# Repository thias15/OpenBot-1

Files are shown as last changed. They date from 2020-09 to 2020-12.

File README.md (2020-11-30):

<a href="https://www.openbot.org/" target="_blank">
  Banner
</a>

<h1 align="center"><a>Turning Smartphones into Robots</a></h1>

<p align="center">
   </a>
   </a>
   </a>
   </a>
   </a>
   </a>
   </a>
   </a>
</p>

<p align="center">
  <span>English</span> |
  <a href="README_CN.md">简体中文</a>
</p>

OpenBot leverages smartphones as brains for low-cost robots. We have designed a small electric vehicle that costs about $50 and serves as a robot body. Our software stack for Android smartphones supports advanced robotics workloads such as person following and real-time autonomous navigation.

## Get started with OpenBot
- Build your own [Robot Body](body/README.md)
- Flash the [Arduino Firmware](firmware/README.md)
- Install the [Android App](android/README.md)
- Train your own [Driving Policy](policy/README.md)

## Get the source code

- You can download the repo as a [zip file](https://github.com/intel-isl/OpenBot/archive/master.zip) and extract it into a folder of your choice.
- You can clone the OpenBot repository from GitHub with the following command:
    ```bash
    git clone https://github.com/intel-isl/OpenBot.git
    ```
- You can fork the OpenBot repository and then clone your local copy. This is recommended, especially if you want to [contribute](CONTRIBUTING.md).

## Citation

Please cite our [paper](docs/paper/OpenBot.pdf) if you use OpenBot.

```bib
@article{openbot2020,
    author    = {Matthias M\"uller and Vladlen Koltun},
    title     = {{OpenBot}: Turning Smartphones into Robots},
    journal   = {arXiv:2008.10631},
    year      = {2020},
}
```

## Video

<a href="https://www.youtube.com/watch?v=qc8hFLyWDOM" >
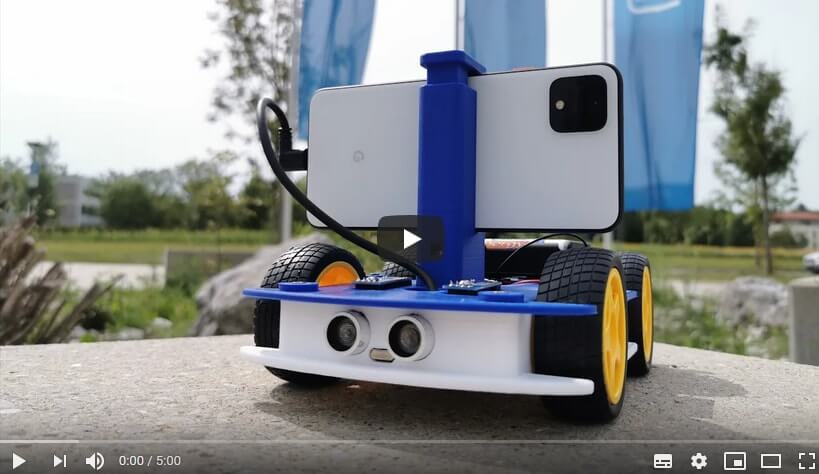
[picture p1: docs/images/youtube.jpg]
youtube video
  
</a>

## Contribute

Please read the [contribution guidelines](CONTRIBUTING.md). If you are not sure where to start have a look at the [open issues](https://github.com/intel-isl/OpenBot/issues).

## Contact

- Join our [Slack](https://join.slack.com/t/openbot-community/shared_invite/zt-jl8ygxqt-WNRNi9yzh7Lu60qui6Nh6w) channel to connect with the OpenBot community.
- Contact us via [Email](mailto:openbot.team@gmail.com)

<a href="https://www.openbot.org//" target="_blank">
  Footer
</a>

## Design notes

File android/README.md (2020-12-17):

# Android App

<p align="center">
  <span>English</span> |
  <a href="README_CN.md">简体中文</a>
</p>

Our application is derived from the [TensorFlow Lite Object Detection Android Demo](https://github.com/tensorflow/examples/tree/master/lite/examples/object_detection/android). We add a data logger and support for game controllers to collect datasets with the robot. Currently, we record readings from following sensors: camera, gyroscope, accelerometer, magnetometer, ambient light sensor, and barometer. Using the Android API, we are able to obtain the following sensor readings: RGB images, angular speed, linear acceleration, gravity, magnetic field strength, light intensity, atmospheric pressure, latitude, longitude, altitude, bearing, and speed. In addition to the phone sensors, we also record body sensor readings (wheel odometry, obstacle distance and battery voltage), which are transmitted via the serial link. Lastly, we record control commands received from a connected game controller, if present. We also integrate several neural networks for person following and autonomous navigation.

## DISCLAIMERS

1. **Safety:** Always make sure you operate in a safe environment. Keep in mind, that your phone could be damaged in a collision! Special 
care is neccessary when using automated control (e.g. person following or driving policy). Make sure you always have a game controller connected and are familiar with the key mapping so you can stop the vehicle at any time. Use at your own risk!
2. **App under development:** The application is under development and may crash or exhibit unexpected behaviour depending on your phone model and version of the operating system. Make sure to test all functionalities with no wheels connected. Use at your own risk!

## Getting Started

### Install the app
You can download the apk from the assets of the [latest release](https://github.com/intel-isl/OpenBot/releases/latest) and just [install](https://www.lifewire.com/install-apk-on-android-4177185) it on your phone directly. Note that that apk is signed with a debug key. If you want the latest app from the master branch, you can also download it from the build artifacts [here](https://github.com/intel-isl/OpenBot/actions?query=workflow%3A%22Java+CI+with+Gradle%22). Note, that it may not be stable. If you would like to make changes to the app later, follow the steps below to compile the app and deploy it on your phone.

### Build the app

#### Prerequisites

- [Android Studio 3.2 or later](https://developer.android.com/studio/index.html) for building and installing the apk.
- Android device and Android development environment with minimum API 21.
- Currently, we use API 28 as compile and target SDK. It should get installed automatically, but if not you can install the SDK manually. Go to Android Studio -> Preferences -> Appearance & Behaviour -> System Settings -> Android SDK. Make sure API 28 is checked and click apply.

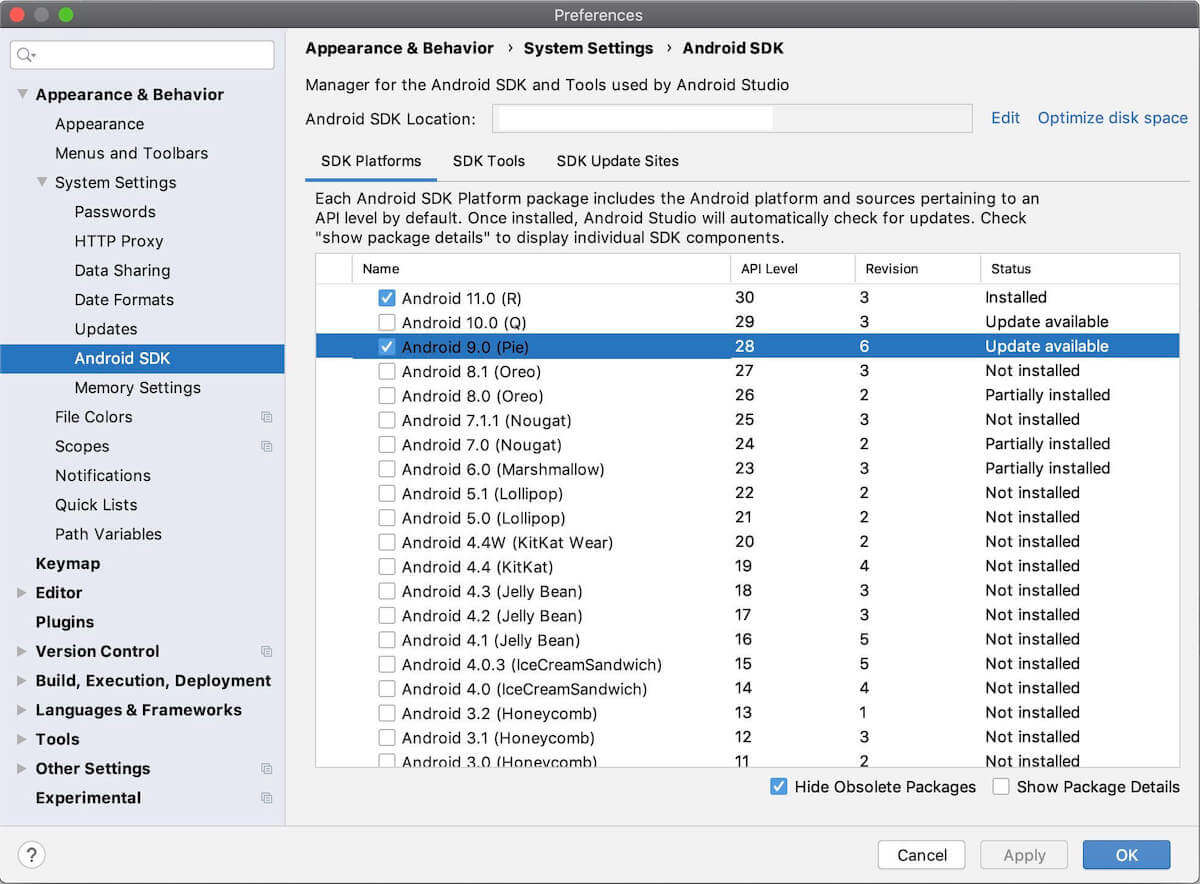
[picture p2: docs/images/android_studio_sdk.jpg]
Android SDK


#### Build process

1. Open Android Studio and select *Open an existing Android Studio project*.
2. Select the OpenBot/android directory and click OK.
3. Confirm Gradle Sync if neccessary. To perform a Gradle Sync manually, click on the gradle icon.
    Gradle Sync
4. Connect your Android device and make sure USB Debugging in the [developer options](https://developer.android.com/studio/debug/dev-options) is enabled. Depending on your development environment [further steps](https://developer.android.com/studio/run/device) might be necessary. You should see your device in the navigation bar at the top now.
  Phone
5. Click the Run button (the green arrow) or select Run > Run 'android' from the top menu. You may need to rebuild the project using Build > Rebuild Project.
  Run
6. If it asks you to use Instant Run, click *Proceed Without Instant Run*.

#### Code Structure

The [TensorFlow Lite Object Detection Android Demo](https://github.com/tensorflow/examples/tree/master/lite/examples/object_detection/android) was used as starting point to integrate TFLite models and obtain the camera feed. The main activity is the [NetworkActivity](app/src/main/java/org/openbot/NetworkActivity.java) which runs the main thread. It inherits from the [CameraActivity](app/src/main/java/org/openbot/CameraActivity.java) which manages the camera and UI. The [SensorService](app/src/main/java/org/openbot/SensorService.java) reads all other phone sensors and logs them. The [env](app/src/main/java/org/openbot/env) folder contains utility classes such as the [GameController](app/src/main/java/org/openbot/env/GameController.java) interface and an [AudioPlayer](app/src/main/java/org/openbot/env/AudioPlayer.java) for the audible feedback. The [tflite](app/src/main/java/org/openbot/tflite) folder contains the model definitions for the [Autopilot](app/src/main/java/org/openbot/tflite/Autopilot.java) and [Detector](app/src/main/java/org/openbot/tflite/Detector.java) networks.

## How to Use the App

<p align="center">
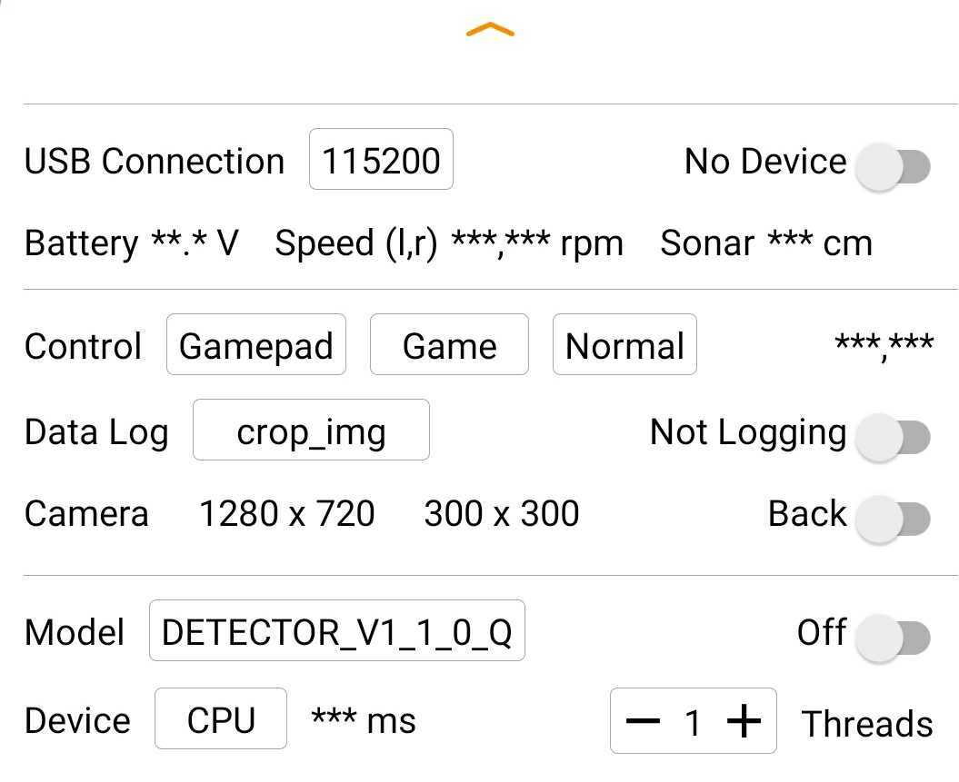
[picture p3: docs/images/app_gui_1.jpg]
  
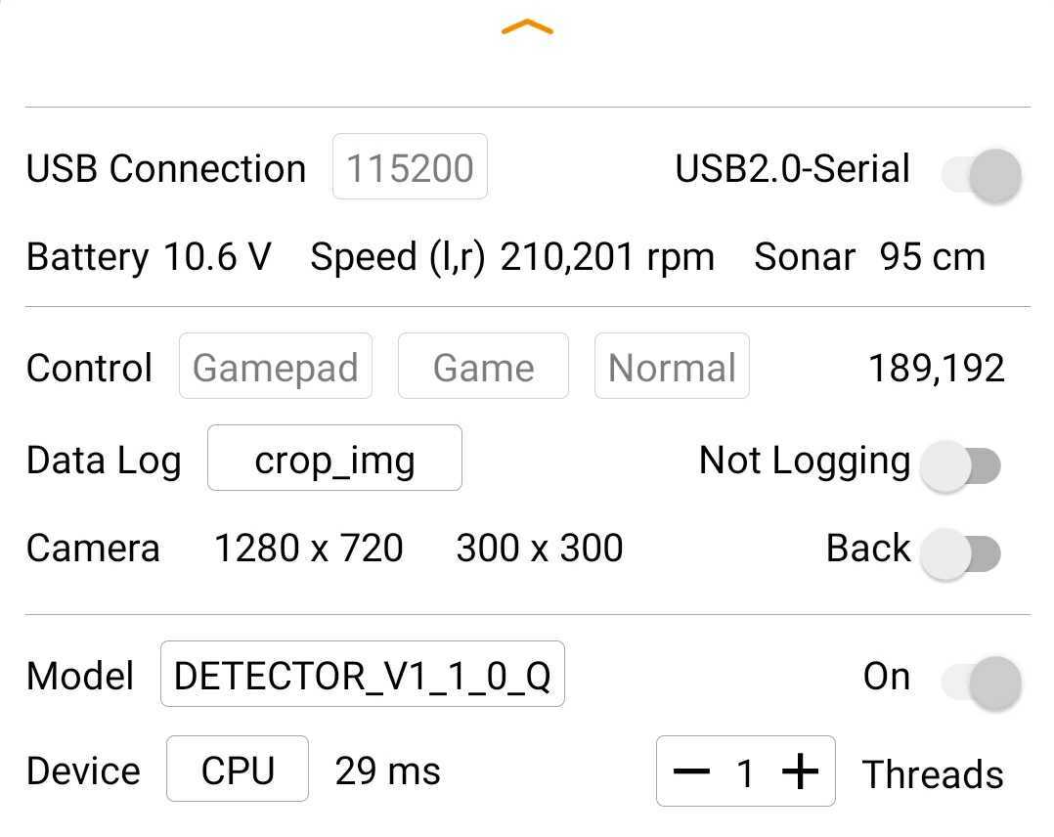
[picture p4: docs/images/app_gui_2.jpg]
  
</p>

### USB Connection

The drop-down menu is used to set the baud rate. The default is 115200 and you should not need to change this unless you mess with the Arduino firmware. The app will attempt to connect automatically, but in case you encounter issues you can use this switch to disconnect/connect.

### Vehicle Status

The field **Battery** displays the battery voltage as measured by the Arduino via the voltage divider. The field **Speed (l,r)** reports the left and right speed of the (front) wheels in rpm. It is measured by the Arduino via the optical wheel speed sensors. The field **Sonar** shows the free space in front of the car in centimeters. It is measured by the Arduino via the ultrasonic sensor. Note, you will only receive values a few seconds after the USB connections has been established.

### Control

The first button is for selecting the **control mode**. Currenlty, the only control mode is **Gamepad**. In the future, it will be possible to control the robot with another smartphone, i.e. **Phone** or via **WebRTC**. 

The second button is for selecting the **drive mode**. There are three different drive modes when using a game controller (e.g. PS4):

- **Game**: Use the right and left shoulder triggers (R2, L2) for forward and reverse throttle and either joystick for steering. This mode imitates the control mode of car racing video games.
- **Joystick**: Use either one of the joysticks to control the robot.
- **Dual**: Use the left and right joystick to control the left and right side of the car. This is raw differential steering.

The third button is for selecting the **speed mode**. There are three different speed modes:

- **Slow**: The voltage applied to the motors is limited to 50% of the input voltage (~6V).
- **Normal**: The voltage applied to the motors is limited to 75% of the input voltage (~9V).
- **Fast**: There is no limit. The full input voltage will be applied to the motors at full throttle (~12V). *This is the default setting for running the neural networks.*

Running at higher speeds will reduce the lifetime of the motors but is more fun. The controls that are sent to the robot are displayed on the right side.

### Data Log

There are four different logging modes:

- **only_sensors**: All sensor data but no images are saved.
- **crop_img**: All sensor data and a cropped images that have the input size of the network are saved. This is the default setting and is what should be used for data collection.
- **preview_img**: All sensor data and a full-size images are saved. This will require a lot of memory and can be slow. However, it is nice for compiling FPV videos.
- **all_imgs**: All sensor data and both cropped and full-size images are saved. This will require a lot of memory and can be slow.

The switch on the right is used to toggle logging on and off. On the game controller this switch can be toggled with the X button. 

### Camera

The first item shows the preview resolution. The second item shows the crop resolution. This is the image that is used as input to the neural networks. You will notice that this resolution changes depending on which model you select below. If you train your own autopilot, make sure to select the `AUTOPILOT_F` model. The crop resolution should show `256x96`. The switch on the right is used to toggle between the rear and the front camera. 

### Model

There are three models that come with the app:

- **DETECTOR_V1_1_0_Q**: This model is used for person following. It uses a SSD object detector with MobileNet V1 backbone. The model is quantized for better performance on embedded devices.
- **DETECTOR_V3_S_Q**: This model is used for person following. It uses a SSD object detector with MobileNet V3 backbone. The model is quantized for better performance on embedded devices.
- **AUTOPILOT_F**: This model is used for autonomous navigation. It will predict controls directly from the camera input. Chances are that it will not work in your environment. You should follow our instructions to train your own [Driving Policy](../policy) and replace it.

The switch on the right is used to turn the network on and off. When the network is running, it produces the controls for the robot and the game controller is disabled. However, you may still use the buttons on the game controller, for example to toggle this switch with the R1 trigger button to regain control of the robot. 

### Device

Use the drop-down menu to select the device on which the neural network should be executed. You have the following choices:

- **CPU**: Using the CPU works on most phones and is the default choice. You can adjust the number of threads to optimize performance. 
- **GPU**: Most smartphones have a GPU. Networks with large inputs such as images often run faster on a GPU.
- **NNAPI**: This will use the [TensorFlow Lite NNAPI delegate](https://www.tensorflow.org/lite/performance/nnapi). Modern smartphones often come with dedicated AI accelerators. The [Neural Network API](https://developer.android.com/ndk/guides/neuralnetworks) (NNAPI) provides acceleration for TensorFlow Lite models on Android devices with Graphics Processing Unit (GPU), Digital Signal Processor (DSP) and Neural Processing Unit (NPU). Note that on some older phones this can be very slow!

If a model is active, the inference speed in [ms] will be displayed next to the device which is running the model.

## Next (optional)

Train your own [Driving Policy](../policy/README.md)

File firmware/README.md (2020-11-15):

# Firmware

<p align="center">
  <span>English</span> |
  <a href="README_CN.md">简体中文</a>
</p>

We use a microcontroller unit (MCU) to act as a bridge between the robot body and the smartphone.  We provide our [firmware](openbot_v1_nano/openbot_v1_nano.ino) for the Arduino Nano with an ATmega328P microcontroller.

## Features

The main task of the MCU is to handle the low-level control of the vehicle and provide readings from low-level vehicle-mounted sensors. The MCU receives the vehicle controls and indicator signals via the serial connection. It converts the controls to PWM signals for the motor controller and toggles the LEDs according to the indicator signal. The Arduino program also keeps track of the wheel rotations by counting the interrupts of optical sensors on the left and right front wheels. It calculates the battery voltage by a scaled moving average of measurements at the voltage divider circuit. It can also measure the distance to obstacles in front of the car with an optional ultrasonic sensor. These measurements are sent back to the Android application through the serial link.

## Setup

First you have to set up your hardware configuration at the beginning of the code. If you did the DIY build (using the L298N motor driver), set `OPENBOT DIY`.
If you used the custom PCB, check the version and set either `OPENBOT PCB_V1` or `OPENBOT PCB_V2`.

Next, you need to configure which features you want to enable. Disabled features are not compiled to save memory and make the code faster.

- Enable the voltage divider by setting `HAS_VOLTAGE_DIVIDER 1` (default: 0)
- Enable the indicator LEDs by setting `HAS_INDICATORS 1` (default: 0)
- Enable the speed sensors by setting `HAS_SPEED_SENSORS 1` (default: 0)
- Enable the ultrasonic sensor by setting `HAS_SONAR 1` (default: 0)
- Enable the median filter for sonar measurements by setting `USE_MEDIAN 1` (default: 0)
- Enable the OLED display by setting `HAS_OLED 1` (default: 0)

### Dependencies

If you have enabled the speed sensors or the ultrasonic sensor, you need to install the [PinChangeInterrupt](https://github.com/NicoHood/PinChangeInterrupt) library. The Arduino Nano only has two external interrupt pins (D2 and D3) and D3 is also one of only six pins that support PWM. Fortunately, it also has three port interrupts that cover all pins on the Arduino. This library parses these port interrupts allowing all pins of the Arduino to be used as interrupts.

If you have enabled the OLED, you need to install the libraries [Adafruit_SSD1306](https://github.com/adafruit/Adafruit_SSD1306) and [Adafruit_GFX Library](https://github.com/adafruit/Adafruit-GFX-Library).

You can install libraries by following these steps:
1. Open the Library Manager: `Tools` :arrow_right: `Manage Libraries`
2. Enter the name of the library in the search bar.
3. Select the latest version and click install. If you have already installed the library it will show and you may be able to update it.

<p float="left">
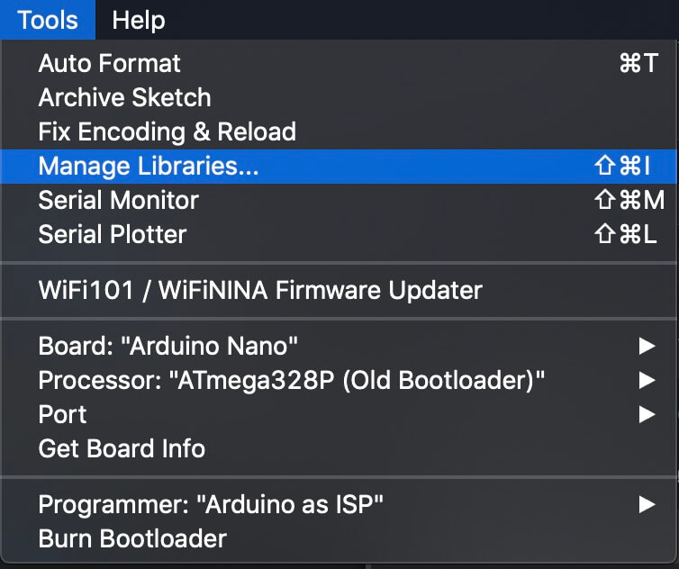
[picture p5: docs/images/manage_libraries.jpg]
  
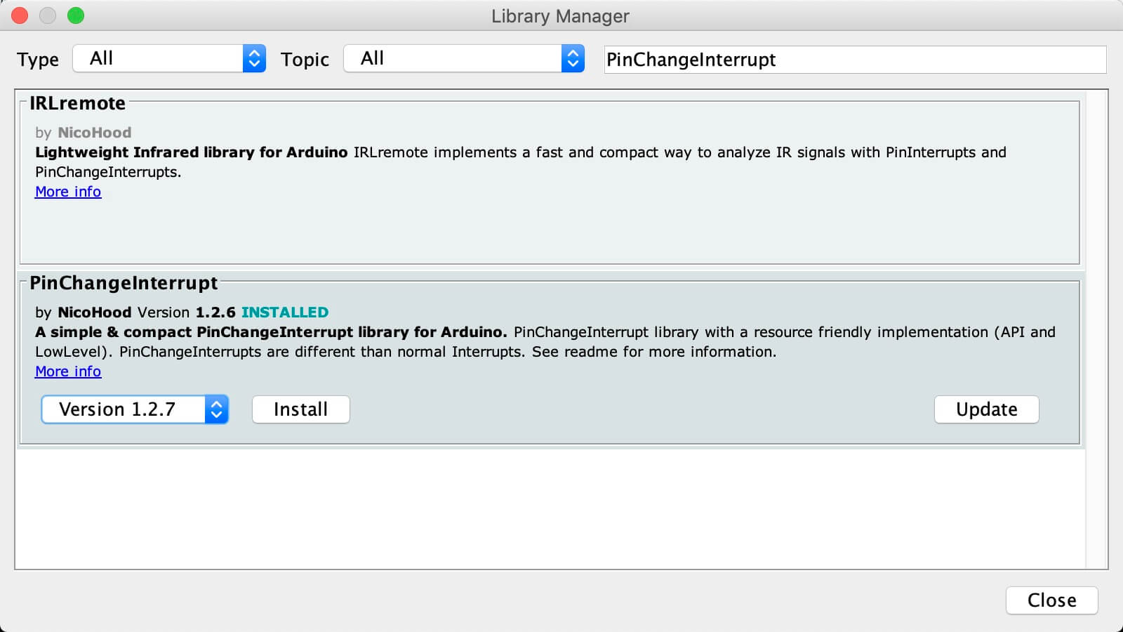
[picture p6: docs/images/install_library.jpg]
   
</p>

### Chinese clone Nano (e.g. US link)

You may need to download the [WCH340](http://www.wch.cn/product/CH340.html) drivers from the chip manufacturer (Chinese):

- [Windows](http://www.wch.cn/downloads/CH341SER_EXE.html)
- [Linux](http://www.wch.cn/download/CH341SER_LINUX_ZIP.html)
- [Mac](http://www.wch.cn/download/CH341SER_MAC_ZIP.html)

## Upload

### Settings

- `Tools` :arrow_right: `Board` :arrow_right: `Arduino AVR Boards` :arrow_right: `Arduino Nano`
- `Tools` :arrow_right: `Processor` :arrow_right: `ATmega328P (Old Bootloader)`
- `Tools` :arrow_right: `Port` :arrow_right: `*Select the USB port*`

The firmware can now be uploaded through `Sketch` :arrow_right: `Upload` or by pressing the upload button (right arrow).
Firmware Upload

:memo: NOTE: Currently, most cheap Arduino Nano boards come with the *Old Bootloader*. However, depending on the seller you may also get one with the new bootloader. So if you are unable to upload the firmware, chances are that you need to change the processor to *ATmega328P*.

### Testing

This section explains how to test all functionalities of the car after the firmware was flashed successfully.

1. Confirm that:
    1. the wheels are not connected to the car
    2. the Arduino is connected to the computer
    3. the correct USB port is selected
2. Open the Serial Monitor: `Tools` :arrow_right: `Serial Monitor`

#### Vehicle Status

You should now see four comma-seperated values that update once per second:

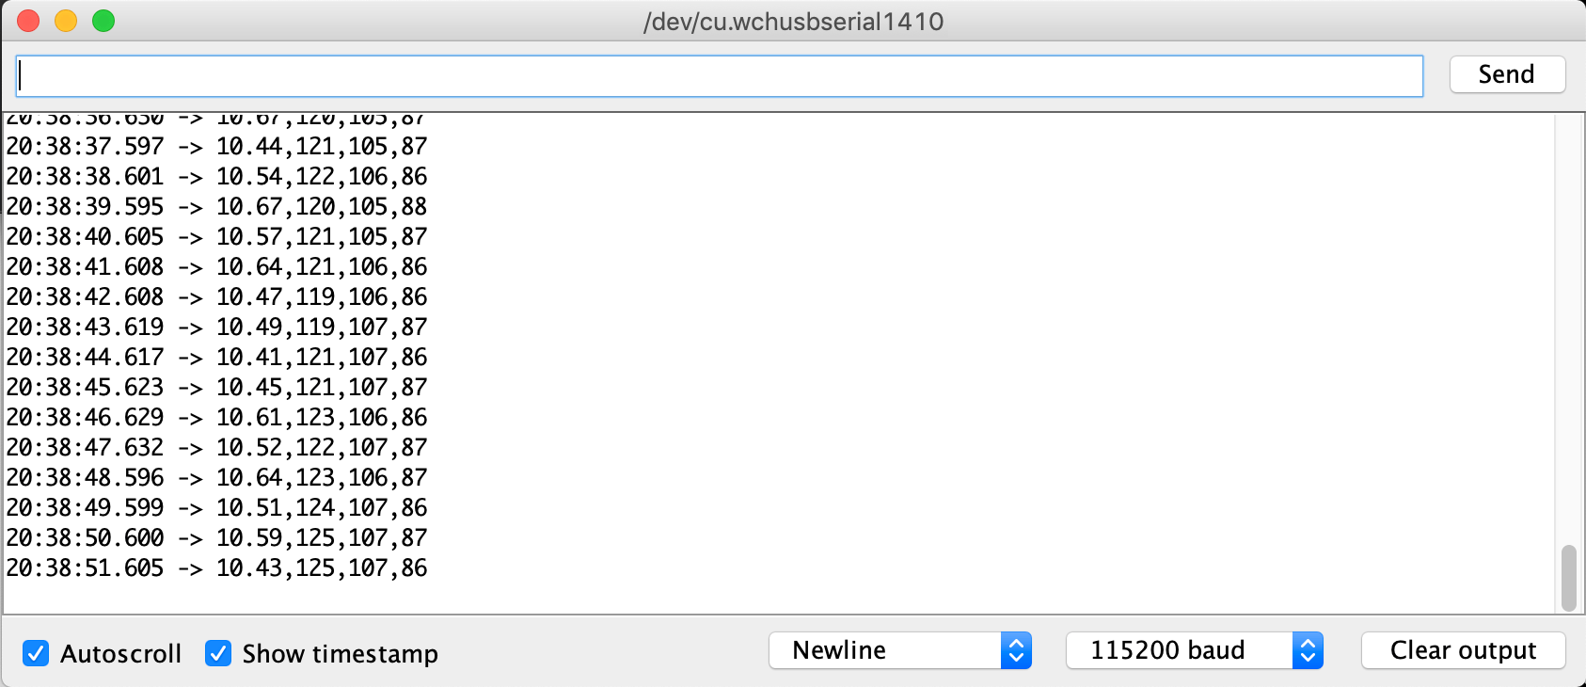
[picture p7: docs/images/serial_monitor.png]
Serial Monitor


- The first value is the battery voltage. If you connect the battery to the car (i.e. turn on the switch), it should show the battery voltage. If you disconnect the battery (i.e. turn off the switch), it should show a small value.
- The second and third values are the raw readings of the speed sensors. Each hole in the encoder disk will increment the counter by plus/minus one depending on the direction. You can set the number of holes with the parameter `DISK_HOLES`. If you are using the stardard disk with 20 holes, there will be 20 counts for each revolution of the wheel. Hence, if you divide the displayed number by 20, you will get the revolutions per second.
- The fourth value is the estimated free space in front of the ultrasonic sensor in cm. If the ultrasonic sensor is disabled or unable to get a reading, it will show `65535`.

#### Vehicle Control

You can also send messages to the Arudino by typing a command into the input field on the top and then pressing send. The following commands are available:

- `c<left>,<right>` where `<left>` and `<right>` are both in the range [-255,255]. A value of `0` will stop the motors. A value of `255` applies the maximum voltage driving the motors at the full speed forward. Lower values lead to proportionlly lower voltages and speeds. Negative values apply the corresponding voltages in reverse polarity driving the motors in reverse.
- `i<cmd>` where `<cmd>` is in the range [-1,1]. A value of `-1` turns on the left indicator LED and a value of `1` turns on the right indicator LED. A value of `0` turns the indicator LEDs off. Only one state at a time is possible.

#### Test procedure

Before you proceed, make sure the tires are removed. You will need the Serial Monitor open to send commands and you will see the messages received from your OpenBot. If you have the OLED display installed, you will also see the vehicle status displayed there in a more human-readable format. The following test procedure can be used to test all functionalities of the car:

1. Turn on the car and observe the battery voltage (first value). You can verify the reading with a multimeter and adjust the `VOLTAGE_DIVIDER_FACTOR` if neccessary.
2. If you have a ultrasonic sensor installed:
    1. Hold your hand in front of the sensor and move it back and forth. You should see the readings (fourth value) change correspondingly.
    2. We have observed that the ultrasonic sensor is very sensitive to vibrations! So it is advisable to make sure you will get reliable readings during operation by performing the following test:
        1. Place the OpenBot with the ultrasonic sensor installed such that there is at least 200cm of free space in front of it. You should see a reading of `200` or more.
        2. Observe the readings on the serial monitor for some time and then enter the command `c128,128`.
        3. If the sensor readings change significantly, you will need to dampen the vibrations transmitted to the ultrasonic sensor from the chassis (e.g. add some silicon, adjust the mounting position).
3. If you have the speed sensors installed:
    1. Make sure, you have plenty of free space in front of the ultrasonic sensor. The reading (fourth value) needs to be at least above the `STOP_THRESHOLD` which is `32` by default. If the ultrasonic sensor is not installed, you should see a reading of `65535`.
    2. Send the command `c128,128`. The motors will start spinning at *slow speed* (50% PWM). The speed sensor readings (second and third value) should be similar to the values in the image above. If you are using the DIY version or a weaker battery, values may be lower. Check that all motors are spinning forward and that the speed sensor readings are positive. Note: If you multiply these values by 3, they correspond to the rpm for the standard disk with 20 holes.
    3. Try sending different controls and observe the speed sensor readings. For example, the command `c-128,-128` will spin all motors backward at *slow speed* (50% PWM). The command `c255,-255` will spin the left motors forward and the right motors backward at *fast speed* (100% PWM). The command `c-192,192` will spin the left motors backward and the right motors forward at *normal speed* (75% PWM).
4. Stop the motors by sending the command `c0,0` or by holding your hand in front of the ultrasonic sensor
5. If you have the indicator LEDs installed, send the command `i-1` and observe the left indicator light flashing. The send the command `i1` and observe the right indicator light flashing. Finally, turn the indicator off by sending the command `i0`.

### No Phone Mode

Before testing the car with a smartphone that has the OpenBot application installed, you can also test the car without a phone first. Simply set the option `NO_PHONE_MODE` to `1`. The car will now drive at *normal_speed* (75% PWM) and slow down as it detects obstacles with the ultrasonic sensor. Once it gets close to the `STOP_THRESHOLD` (default: 32cm), it will start turning in a random direction and turn on the LED on that side. If the estimated free space in front of the car falls below the `STOP_THRESHOLD`, it will slowly go backwards and both LEDs will turn on. Note that both the car and the Arduino need to be powered. The Arduino can be powered by connecting the 5V pin to the 5V output of the L298N motor driver, or by connecting the USB cable to a power source (e.g. phone).

Before running the car, we recommend to remove the tires, connect the Arduino to a computer and observe the serial monitor like in the section [Testing](#testing). The output on the serial monitor is a bit easier to parse (same as OLED) and shows the battery voltage, the rpm for the left and right motors and the estimated free space in front of the car. You can move a large object back and forth in front of ultrasonic sensor and observe the speed of the motors changing.

:warning: WARNING: If you do not have an ultrasonic sensor installed or if it is disabled, the car will just drive forward at *normal_speed* (75% PWM) and will eventually collide. Even with the sensor installed, the car may collide occasionally due to noisy readings.

## Using other MCUs (requirements)

You can use any other MCU with the following features:

- 1x USB-to-TTL Serial (communication with the smartphone)
- 4x PWM output (control the motors)
- 1x analog pin for battery monitoring
- 2x digital pin for the speed sensors
- 1x digital pin for the ultrasonic sensor (optional)
- 2x digital pin for the indicator LEDs (optional)

## Next

Compile and run the [Android App](../android/README.md)

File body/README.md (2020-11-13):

# OpenBot: Robot Body

<p align="center">
  <span>English</span> |
  <a href="README_CN.md">简体中文</a>
</p>

We have designed a body for a wheeled robot which relies on low-cost, readily available hobby hardware.
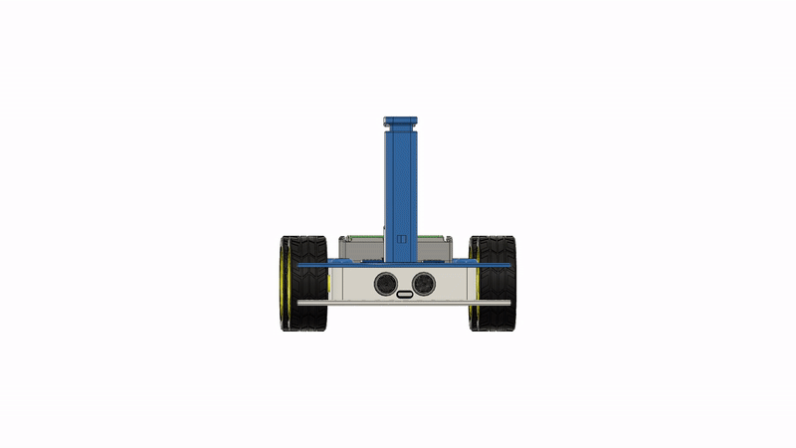
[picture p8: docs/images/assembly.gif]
Assembly


## Chassis

### 3D printing

You will need to print the following parts in order to build your OpenBot.

1) body_bottom ([STL](cad/regular_body/body_bottom.stl), [STEP](cad/regular_body/body_bottom.step))
2) body_top ([STL](cad/regular_body/body_top.stl), [STEP](cad/regular_body/body_top.step))
3) phone_mount_bottom ([STL](cad/phone_mount/phone_mount_bottom.stl), [STEP](cad/phone_mount/phone_mount_bottom.step))
4) phone_mount_top ([STL](cad/phone_mount/phone_mount_top.stl), [STEP](cad/phone_mount/phone_mount_top.step))

For the above parts, your build plate needs to be at least 240mmx150mm.

Since a lot of common 3D printers have a smaller build volume, we have also made a [slim body](cad/slim_body/README.md) which fits on a 220mmx220mm build plate at 45 degrees.

For printing on 3D printers with even smaller build volumes, there is also a [glueable body](cad/glue_body/README.md) which fits on a 150mmx140mm build plate. Thanks to @sloretz.

On an Ultimaker S5, we achieved good results with the following settings:

- layer height: 0.2mm
- wall thickness: 1.5mm
- infill density: 20%
- infill pattern: grid
- print speed 80 mm/s
- no support

We were able to print the chassis with PLA, ABS and CPE. In our experience the print was not affected very much by the print settings. However, if you have the patience, printing slower and with smaller layer height will improve the print. Also adding a support structure can improve the print, but it will require additional work to remove afterwards.

Before you proceed with the build, you may need to clean the 3D print.
<p float="left">
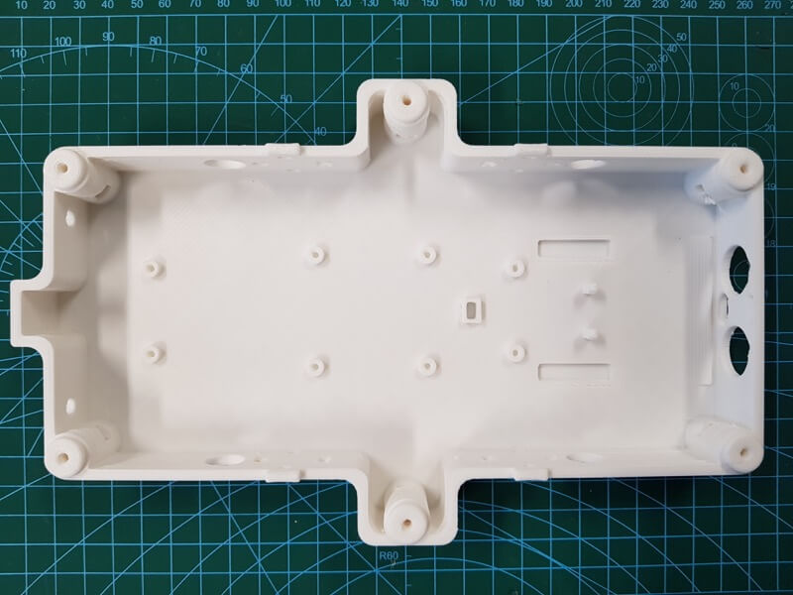
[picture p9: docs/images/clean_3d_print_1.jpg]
  
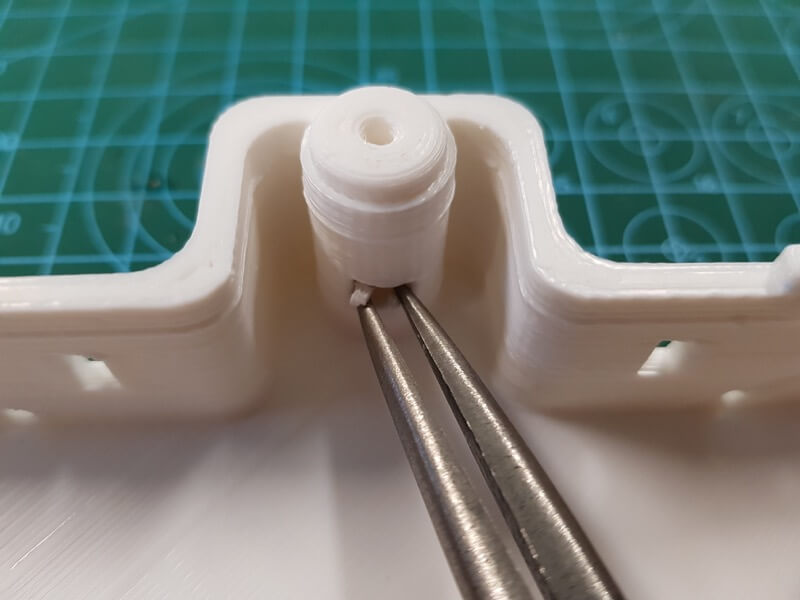
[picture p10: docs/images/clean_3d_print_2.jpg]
   
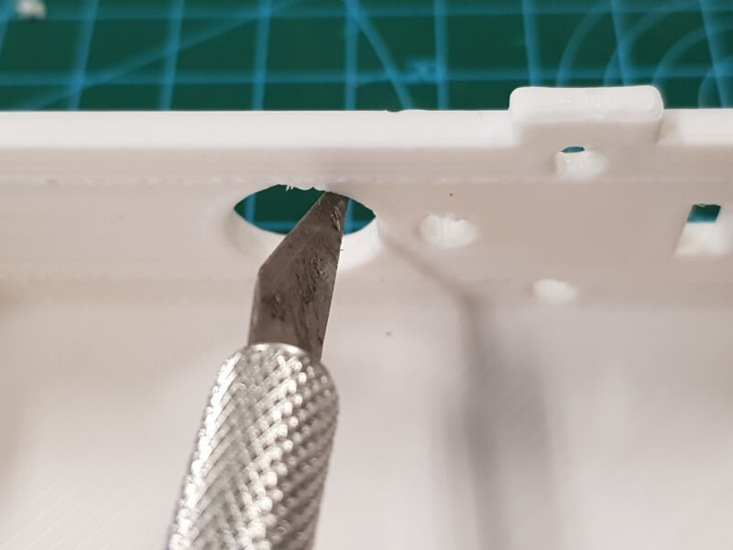
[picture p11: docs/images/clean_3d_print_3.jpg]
  
</p>

### Alternatives

If you do not have access to a 3D printer, there are several Arduino robot car kits available which you can use as a starting point. These kits come with a chassis, motors and accessories. We recommend to get a basic kit, since you won't need a lot of the electronics and sensors of the more expensive kits. Here are some options:

- Perseids DIY Robot Smart Car Chassis Kit ([EU](https://www.amazon.de/dp/B07DNXBNHY), [US](https://www.amazon.com/dp/B07DNXBFQN))
- SZDoit 4WD Smart Metal Robot Car Chassis Kit ([US](https://www.amazon.com/dp/B083K4RKBP), [AE](https://www.aliexpress.com/item/33048227237.html))
- Joy-it Robot Car Kit 01 ([EU](https://www.amazon.de/dp/B073ZGJF28))
- Smart Car Kit 4WD Smart Robot Car Chassis Kit ([AE](https://www.aliexpress.com/item/4001238626191.html))

You will also need a phone mount. Here is one option:

- Mpow Dashboard Car Phone Mount ([EU](https://www.amazon.de/dp/B0762GS7MS), [US](https://www.amazon.com/dp/B08BYFP9BZ))

You can also get creative and build your own OpenBot chassis and phone mount using a material of your choice (e.g. wood, cardboard, styrofoam, etc.). If you do, please post some pictures on the [Slack channel](https://github.com/intel-isl/OpenBot#contact) so others can admire your creativity. Here is one example by [@custom-build-robots](https://custom-build-robots.com/roboter/openbot-dein-smartphone-steuert-ein-roboter-auto-chassis-bauen/13636):

<p float="left">
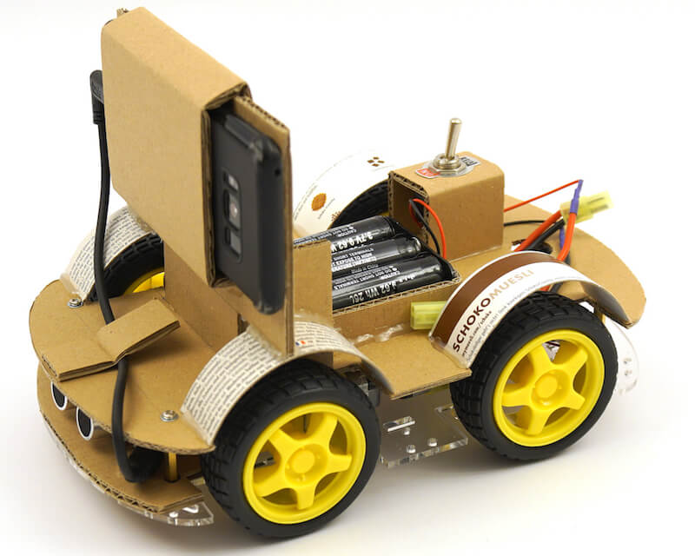
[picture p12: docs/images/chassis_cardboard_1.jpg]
  
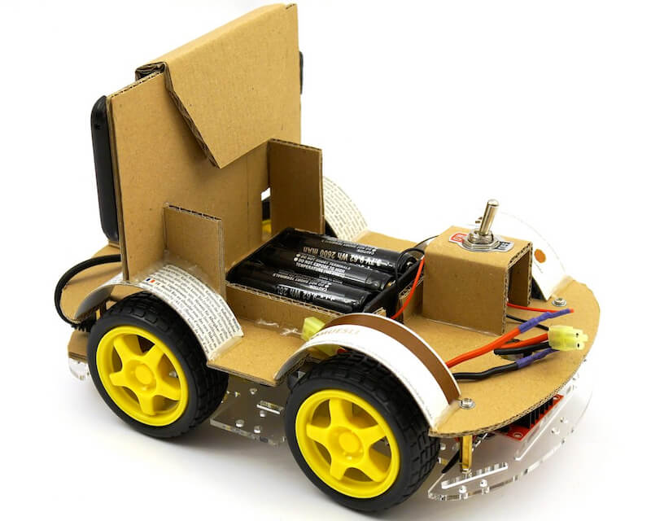
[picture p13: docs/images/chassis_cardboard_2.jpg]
  
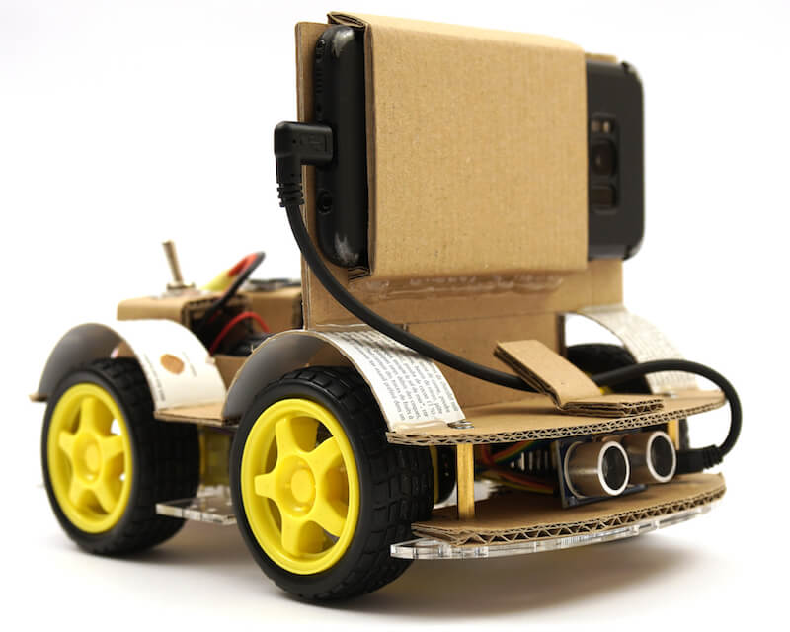
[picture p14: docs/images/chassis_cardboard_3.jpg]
  
</p>

## Assembly

There are two different options for assembly of the robot, DIY and PCB. The DIY approach relies on the popular L298N motor driver and is recommended for hobbyists with some electronics experience. It requires a fair amount of wiring, especially if all the sensors and LEDs are installed. However, all components are readily available in most contries and especially for single builds or just to try out the project, the DIY option is recommended. In order to reduce the wiring and make assembly easier, we have also developed a [custom PCB](pcb). This is recommended if you desire a cleaner build or want to build multiple OpenBots.

### Bill of materials

Our robot body relies on readily available hobby electronics. We provide links for Germany (EU) and the United States (US) with fast shipping. If you have the patience to wait a bit longer, you can also get the compoenents a lot cheaper from AliExpress (AE). You will need the following components.

#### Required components

- 1x Arduino Nano ([EU](https://www.amazon.de/dp/B01MS7DUEM), [US](https://www.amazon.com/dp/B00NLAMS9C), [AE](https://www.aliexpress.com/item/32866959979.html))
- 4x TT motors with tires ([EU](https://www.conrad.de/de/p/joy-it-com-motor01-getriebemotor-gelb-schwarz-passend-fuer-einplatinen-computer-arduino-banana-pi-cubieboard-raspbe-1573543.html), [US](https://www.amazon.com/dp/B081YQM55P), [AE](https://www.aliexpress.com/item/4000126948489.html))
- 3x 18650 battery ([EU](https://www.conrad.de/de/p/conrad-energy-18650-usb-spezial-akku-18650-li-ion-3-7-v-1400-mah-1525536.html), [US](https://www.amazon.com/dp/B083K4XSKG), [AE](https://www.aliexpress.com/item/32352434845.html))
- 1x 18650 battery holder([EU](https://www.amazon.de/dp/B075V25QJ9), [US](https://www.amazon.com/dp/B07DWQYD7H), [AE](https://www.aliexpress.com/item/33037738446.html))
- 1x USB OTG cable ([EU](https://www.amazon.de/gp/product/B075M4CQHZ) ,[US](https://www.amazon.com/dp/B07LBHKTMM), [AE](https://www.aliexpress.com/item/10000330515850.html))
- 1x spring or rubber band ([EU](https://www.amazon.de/gp/product/B01N30EAZO/), [US](https://www.amazon.com/dp/B008RFVWU2), [AE](https://www.aliexpress.com/item/33043769059.html))
- 16x M3x25 screw ([EU](https://www.amazon.de/dp/B07KFL3SSV), [US](https://www.amazon.com/dp/B07WJL3P3X), [AE](https://www.aliexpress.com/item/4000173341865.html))
- 16x M3 nut ([EU](https://www.amazon.de/dp/B07JMF3KMD), [US](https://www.amazon.com/dp/B071NLDW56), [AE](https://www.aliexpress.com/item/32977174437.html))
- 6x M3x5 screw ([EU](https://www.amazon.de/dp/B01HBRG3W8), [US](https://www.amazon.com/dp/B07MBHMLL2), [AE](https://www.aliexpress.com/item/32892594230.html))
- Dupont cables ([EU](https://www.amazon.de/dp/B07KYHBVR7), [US](https://www.amazon.com/dp/B07GD2BWPY), [AE](https://www.aliexpress.com/item/4000766001685.html))

#### Optional components

- 2 x Speed Sensor ([EU](https://www.conrad.de/de/p/joy-it-sen-speed-erweiterungsmodul-passend-fuer-einplatinen-computer-arduino-banana-pi-cubieboard-raspberry-pi-pc-1646891.html), [US](https://www.amazon.com/dp/B081W2TY6Q), [AE](https://www.aliexpress.com/i/32850602744.html))
- 1x Ultrasonic Sensor ([EU](https://www.amazon.de/dp/B00LSJWRXU), [US](https://www.amazon.com/dp/B0852V181G/), [AE](https://www.aliexpress.com/item/32713522570.html))
- 1x On/Off Switch ([EU](https://www.amazon.de/dp/B07QB22J62), [US](https://www.amazon.com/dp/B01N2U8PK0), [AE](https://www.aliexpress.com/item/1000005699023.html))
- 2x Orange LED 5mm ([EU](https://www.amazon.de/gp/product/B01NCL0UTQ), [US](https://www.amazon.com/dp/B077XD7MVB), [AE](https://www.aliexpress.com/item/4000329069943.html))
- 1x OLED display ([EU](https://www.amazon.de/dp/B079H2C7WH), [US](https://www.amazon.com/dp/B085NHM5TC), [AE](https://www.aliexpress.com/item/4001268387467.html))

#### DIY components (Option 1)

- 1x L298N Motor Driver ([EU](https://www.conrad.de/de/p/joy-it-motormodul-2-u-4-phasen-6-bis-12v-1573541.html), [US](https://www.amazon.com/dp/B085XSLKFQ), [AE](https://www.aliexpress.com/item/32994608743.html))
- (Optional) Resistors (2x 150<span>&#8486;</span> for the LEDs and a 20 k<span>&#8486;</span> and 10k<span>&#8486;</span> for the voltage divider)
- (Combo) 4x TT motors & tires + 2x L298N + dupont cables ([US](https://www.amazon.com/dp/B07ZT619TD))
- (Combo) 4x TT motors & tires + wires + screws ([US](https://www.amazon.com/dp/B07DRGTCTP))

#### PCB components (Option 2)

- 1x [Custom PCB](pcb)
- 5x Micro JST PH 2.0 cable ([EU](https://www.amazon.de/gp/product/B07449V33P), [US](https://www.amazon.com/dp/B07449V33P), [AE](https://www.aliexpress.com/item/32963304134.html))

### Build instructions

**Tip:** Click on the images to open them in full resolution in a new tab.

#### Option 1: DIY

<p float="left">
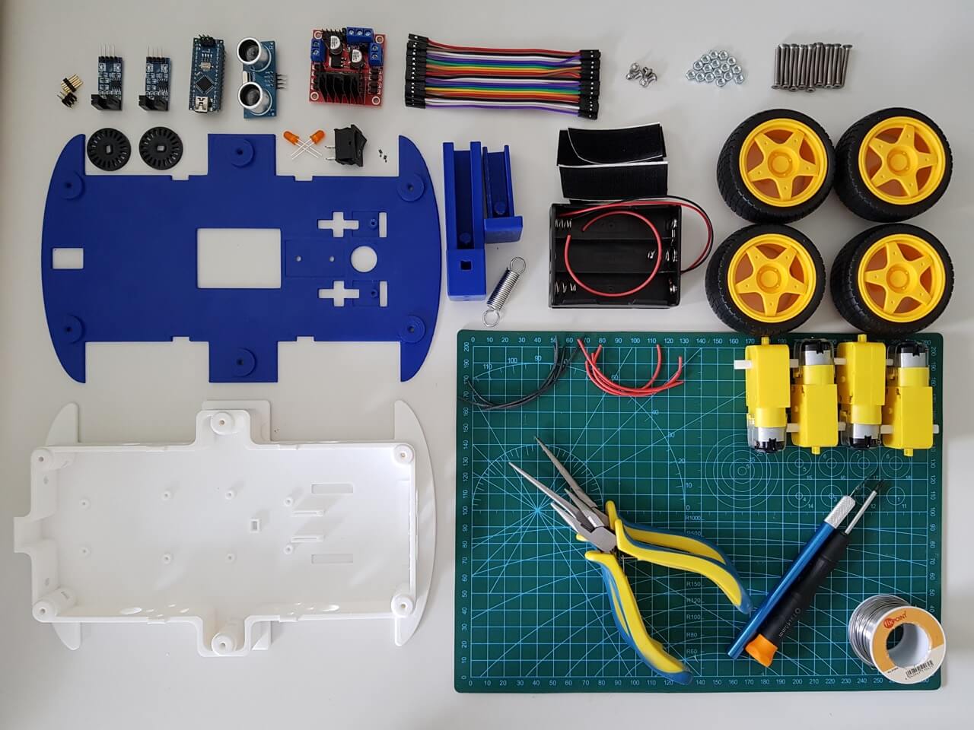
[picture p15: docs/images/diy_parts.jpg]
  
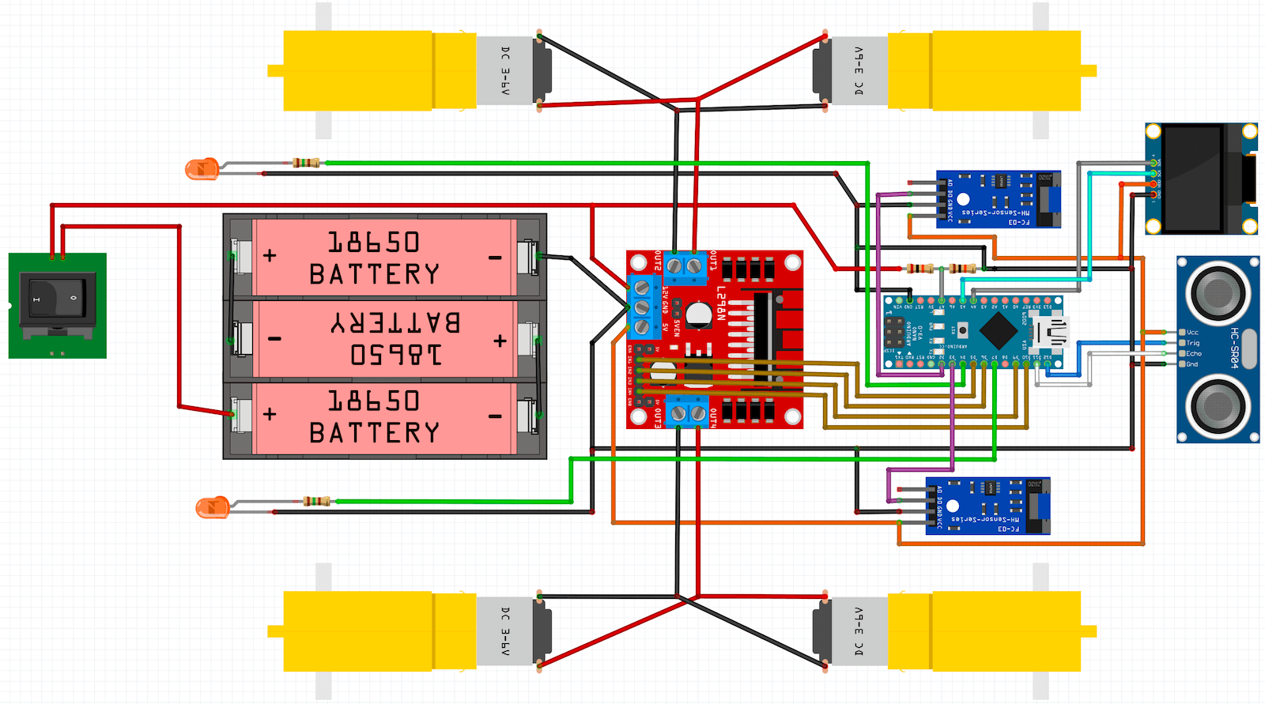
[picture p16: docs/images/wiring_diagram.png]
   
</p>

**Tip:** To make all the wiring easier you can build a small power distributor for the 5V and GND connections by soldering a 6x2 male header to a perfboard. Then connect the power distributor with the 5V / GND of the motor driver.

1. Solder wires to the motors and add the encoder disks to the two front motors if you intend to use the speed sensors.
    <p float="left">
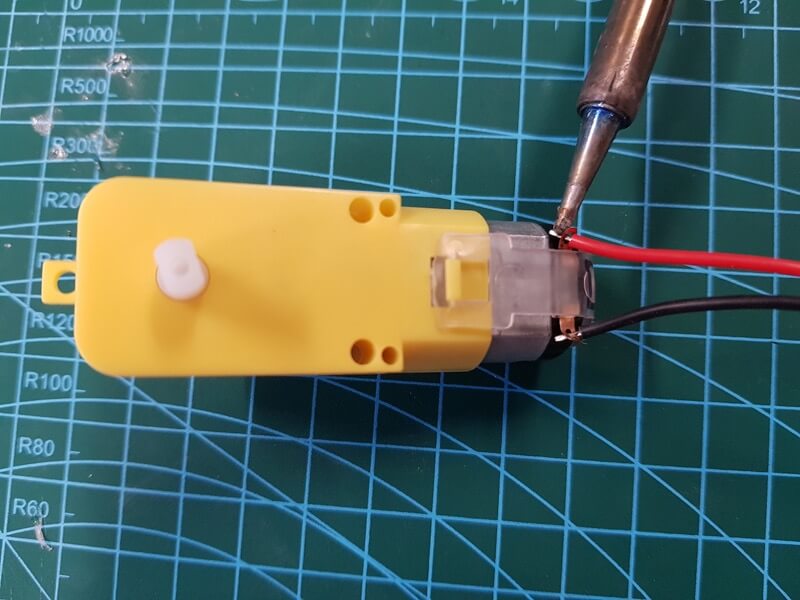
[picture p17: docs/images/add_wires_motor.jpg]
      
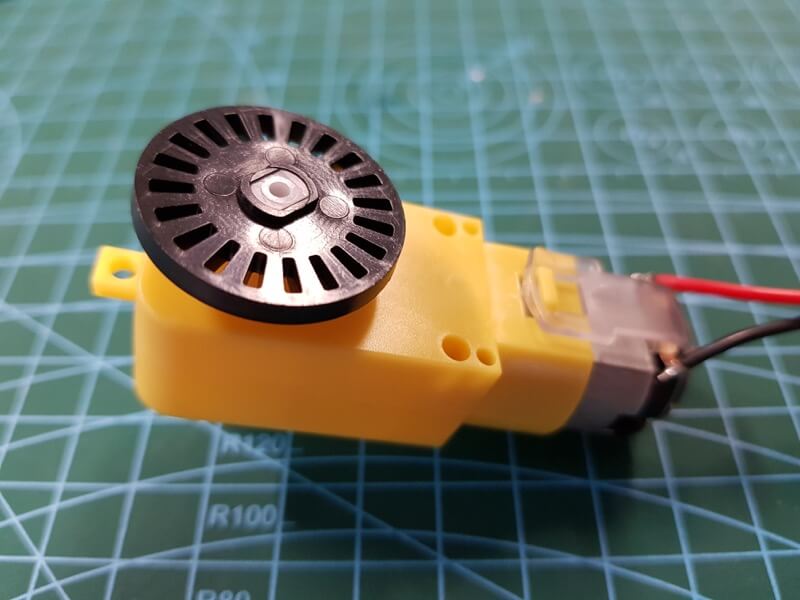
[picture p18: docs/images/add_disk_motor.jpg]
       
    </p>
2. Insert the positive and negative leads of the two left motors into OUT1 (+) and OUT2 (-) of the L298N board. Insert the positive and negative leads of the two right motors into OUT4 (+) and OUT3 (-) of the L298N board.
3. Mount the motors with eight M3x25 screws and nuts.
    <p float="left">
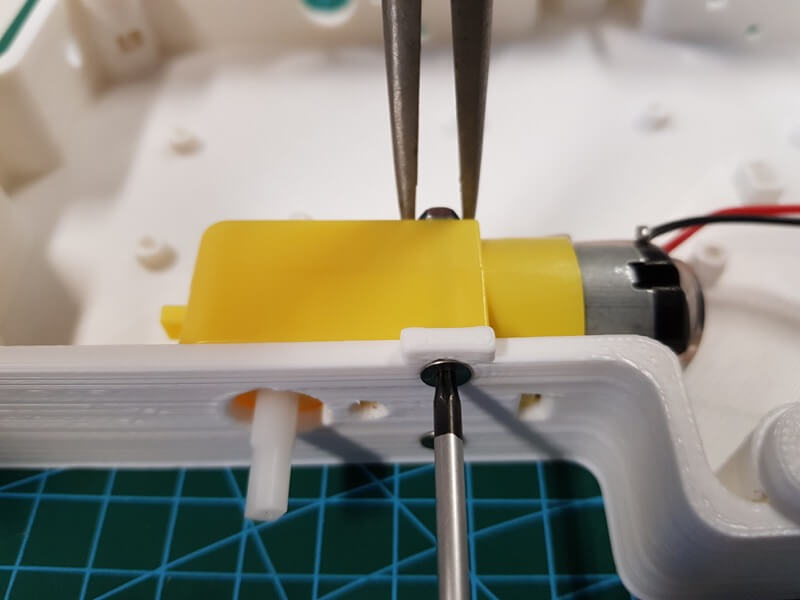
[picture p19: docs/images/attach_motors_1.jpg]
      
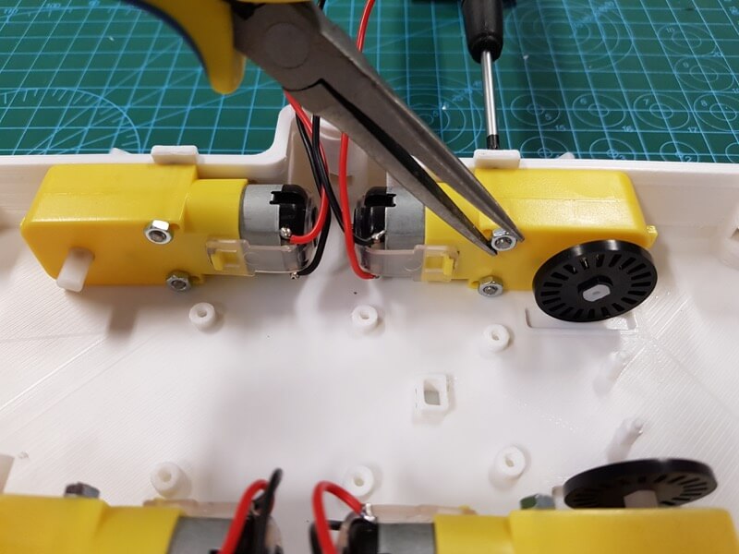
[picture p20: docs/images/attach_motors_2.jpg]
       
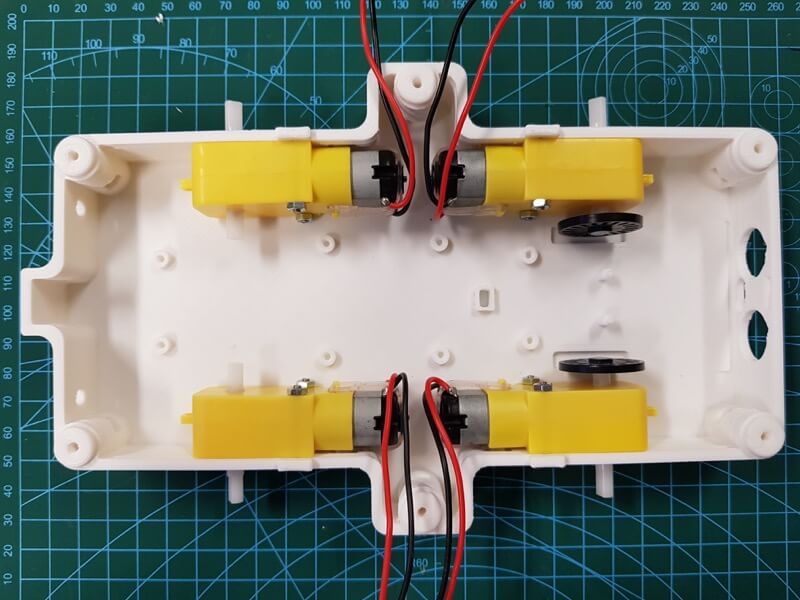
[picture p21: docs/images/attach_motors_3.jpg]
      
    </p>
4. Mount the L298N with four M3x5 screws
5. (Optional) Install the ultrasonic sensor and replace the angled connector with a straigt one (or carefully bend the pins).
    <p float="left">
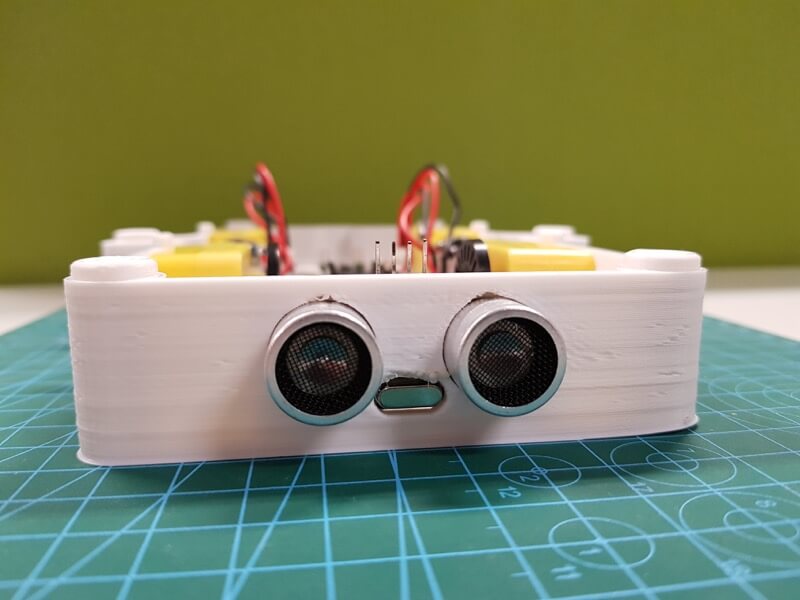
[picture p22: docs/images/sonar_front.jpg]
      
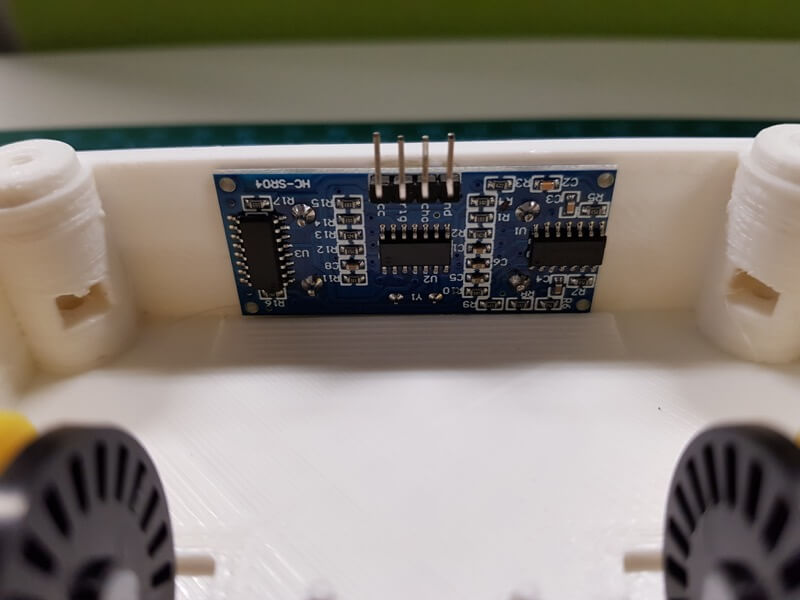
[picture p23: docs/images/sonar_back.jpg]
       
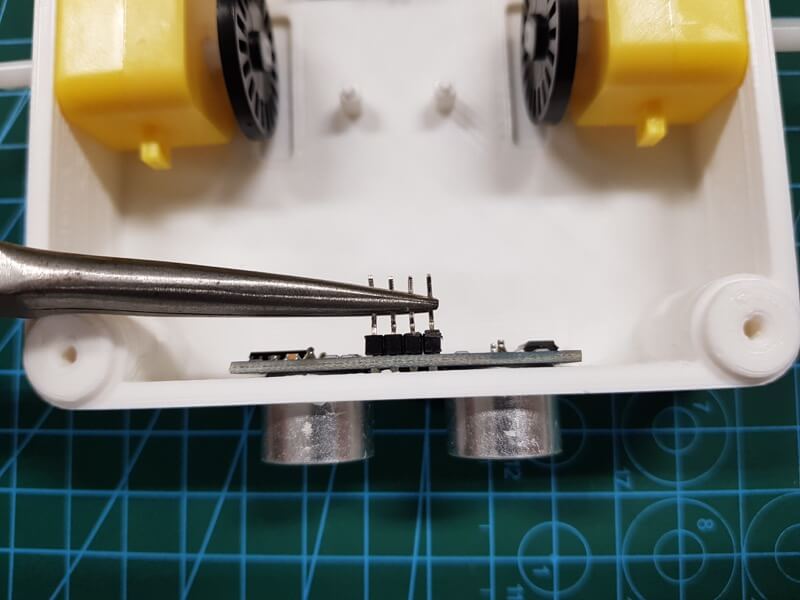
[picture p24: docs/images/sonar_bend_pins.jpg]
      
    </p>
6. (Optional) Install the orange LEDs for the indicator signals.
    <p float="left">
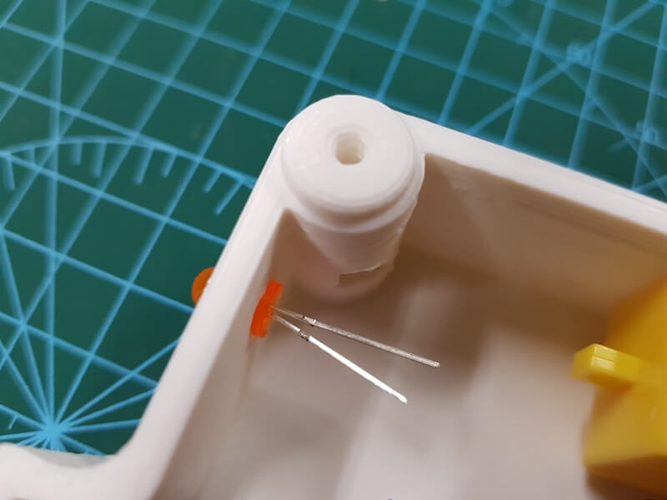
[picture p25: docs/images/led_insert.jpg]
      
       
      
    </p>
7. Mount the bottom of the phone mount to the top plate using two M3x25 screws and nuts.
    <p float="left">
      
       
      
    </p>
8. Insert the top of the phone mount and install the spring or rubber band.
    <p float="left">
      
       
    </p>
9. Replace the angled connector with a straigt one (or carefully bend the pins) and then mount the speed sensors with one M3x5 screw each.
    <p float="left">
      
       
      
    </p>
10. Install the battery case (e.g. velcro).
    <p float="left">
      
       
      
    </p>
11. (Optional) Insert the on/off switch put it in the current path.
    1. Push the switch into the appropriate opening until you hear a click.
    2. Solder the red wires (12V) of the battery case and the power cable each to one of the pins of the switch. Connect the black wires (GND), and cover the connection with some heatshrink.
    3. Fix the cables with some tape.
    <p float="left">
      
       
      
    </p>
12. (Optional) Attach the OLED display.
13. Connect the PWM inputs of the L298N to pins D5, D6, D9 and D10 of the Arduino.
14. Connect the speed sensors and ultrasonic sensor to 5V and GND.
15. Connect pin D0 of the speed sensors to pins D2 (left) and D3 (right) of the Arduino.
16. Connect pins Echo and Trigger of the ultrasonic sensor to pins D11 and D12 of the Arduino respectively.
17. (Optional) Connect the LEDs to pins D4 (left) and D7 (right) of the Arduino and GND. We recommend to add a 150 Ohm resistor in series to limit the current draw.
18. (Optional) Connect the voltage divider to pin A7 of the Arduino. It is used to measure the battery voltage.
19. (Optional) Connect the OLED display (SSD1306 chip) via the I2C bus to the Arduino Nano
    1. Connect the VIN and GND pins of the display to 5V and GND.
    2. Connect the SCL pin of the display to the A5 pin.
    3. Connect the SDA pin of the display to the A4 pin.
20. Connect the power cables to +12V and GND of the L298N.
21. Connect the USB cable to the Arduino and route it through the top cover.
22. Insert six M3 nuts into the bottom plate and mount the top cover with six M3x25 screws.
23. Install the wheels.

#### Option 2: Custom PCB

1. Solder wires with Micro JST PH 2.0 connectors to the motors and add the encoder disks to the two front motors if you intend to use the speed sensors.
    <p float="left">
      
       
    </p>
2. Mount the motors with eight M3x25 screws and nuts.
    <p float="left">
      
       
      
    </p>
3. Connect the left two motors to M3 and M4 and the right two motors to M1 and M2.
    <p float="left">
      
    </p>
4. Mount the PCB with four M3x5 screws and the motors with eight M3x25 screws and nuts.
    <p float="left">
      
      
    </p>
5. Follow steps 5-12 from the DIY option.
6. Connect the ultrasonic sensor (VCC/+, Trig, Echo, GND/-) to the 4-pin header labeled *SONAR* on the PCB.
    <p float="left">
      
    </p>
7. Connect the left and right indicator signals (orange LEDs) to the 2-pin headers labeled *SIGNAL_L* and *SIGNAL_R* on the PCB. The longer leg is + and the shorter one -.
8. Connect the left and right speed sensors (VCC/+, GND/-, D0) to the 3-pin headers labeled *SPEED_L* and *SPEED_R*.
9. (Optional) Connect the OLED display (SSD1306 chip) to the IO2 header on the PCB.
    1. Connect the VIN and GND pins of the display to 5V and GND.
    2. Connect the SCL pin of the display to the A5 pin.
    3. Connect the SDA pin of the display to the A4 pin.
10. Connect the power cables to Vin (Micro JST PH 2.0 connector) of the PCB.
11. Follow steps 21-23 from the DIY option.

## Next

Flash the [Arduino Firmware](../firmware/README.md)

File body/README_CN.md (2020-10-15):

# OpenBot 中文版说明

<p align="center">
  <a href="README.md">English</a> |
  <span>简体中文</span>
</p>

我们为轮式机器人设计了一个车身，该车身依赖于低成本，随时可用的业余爱好硬件。

Assembly

## 3D打印机身

您将需要打印以下部分用来组装您的OpenBot机器车。

1) 车身底部 ([STL](cad/body_bottom.stl), [STEP](cad/body_bottom.step))
2) 车身顶部 ([STL](cad/body_top.stl), [STEP](cad/body_top.step))
3) 手机支架底部 ([STL](cad/phone_mount_bottom.stl), [STEP](cad/phone_mount_bottom.step))
4) 手机支架顶部 ([STL](cad/phone_mount_top.stl), [STEP](cad/phone_mount_top.step))

对于上述零件，你的构建板至少需要240mmx150mm。

由于很多常见的3D打印机的构建体积较小，我们还制作了一个[slim body](cad/slim_body/README_CN.md)，它适合在220mmx220mm的构建板上以45度的角度进行构建。

对于在3D打印机上打印更小的构建量，还有一个[glueable body](cad/glue_body/README_CN.md)，适合在150mmx140mm的构建板上打印。感谢@sloretz。

在Ultimaker S5上，我们通过以下设置获得了良好的效果：

- 层高：0.2mm
- 壁厚：1.5mm
- 填充密度：20％
- 填充图案：网格
- 打印速度80毫米/秒
- 无支持

我们能够使用PLA，ABS和CPE打印机箱。 根据我们的经验，打印设置不受打印设置的影响很大。 但是，如果您有耐心，则打印速度较慢且层高度较小的纸张会改善打印质量。 另外，添加支撑结构可以改善打印效果，但是添加的支撑之后需要进行额外的工作才能去除。

中国用户可以在淘宝找商家打印。注意以下事项：

- PLA材料 3D打印机身
  - 层高:0.2mm
  - 壁厚:1.5mm
  - 填充密度:20％
  - 填充图案:网格
  - 机身数量 共4块
  - 建议价格:¥120.00以内(含邮费)

## 部件

机器人的组装有两种不同的选择：DIY和PCB。 DIY方法依赖于流行的L298N电机驱动器，建议具有一定电子经验的业余爱好者使用。 它需要大量的接线，尤其是在安装所有传感器和LED的情况下。但是，在大多数情况下，所有组件都很容易获得，尤其是对于只需要制作一部车身或只是为了尝试项目，建议使用DIY选项。同时为了减少布线并简化组装，我们还开发了[custom PCB](pcb)。 如果您想要制作过程更简单或想要多个OpenBots车身，则建议这样做。

### 料清单

我们的机器人主体依靠随时可用的爱好电子设备。 我们提供快速运输到德国（EU）和美国（US）的链接。 如果您有耐心等待更长的时间，您也可以从速卖通（AE）那里购买便宜得多的组件。中国用户建议在淘宝购买。您将需要以下组件。

(通用)

- Arduino nano V3.0 CH340G 改进版
  - 数量 1
  - 价格:¥5.49
  - [淘宝购买](https://s.click.taobao.com/iI1K4xu)
- 直流减速电机+智能小车车轮cbot 
  - 数量 4
  - 价格:¥10.00
  - [淘宝购买](https://s.click.taobao.com/GA955xu)
- 18650大容量充电锂电池
  - 数量 3
  - 价格:¥16.80
  - [淘宝购买](https://s.click.taobao.com/5jj45xu) , [领券](https://s.click.taobao.com/ww855xu)
- BS电池盒 5号/五号/七号7号18650电池盒 
  - 数量 1
  - 价格:¥1.59
  - [淘宝购买](https://s.click.taobao.com/tzcJ4xu)
- T型口转type-c 连接线
  - 数量 1
  - 价格:¥25.00
  - [淘宝购买](https://s.click.taobao.com/FKmZVvu)
- 304不锈钢拉簧拉力拉伸带钩弹簧 
  - 数量 1
  - 价格:¥0.60
  - [淘宝购买](https://s.click.taobao.com/nj1Kzwu)
- M2.5 M3 304不锈钢圆头一字螺丝*25mm
  - 数量 16
  - 价格:¥4.00
  - [淘宝购买](https://s.click.taobao.com/GGF45xu)
- 304不锈钢六角螺母小螺丝帽
  - 数量 16
  - 价格:¥18.00
  - [淘宝购买](https://s.click.taobao.com/3roD0xu)
- M3* 5 螺丝
  - 数量 6
  - 价格:￥2.18
  - [淘宝购买](https://s.click.taobao.com/WHO55xu) , [领券](https://s.click.taobao.com/6Np45xu)
- 杜邦线
  - 数量 1
  - 价格:¥2.80
  - [淘宝购买](https://s.click.taobao.com/nfSJ4xu)

(仅DIY)

- L298N 开发板
  - 数量 1
  - 价格:¥14.92
  - [淘宝购买](https://s.click.taobao.com/pyt45xu) , [领券](https://s.click.taobao.com/C1nJ4xu)
- (可选) 电阻器(2x 150<span>&#8486;</span>用于LED，20k<span>&#8486;</span>和10k<span>&#8486;</span>用于分压器)
- (Combo) 4x TT马达和轮胎+2x L298N+dupont电缆 ([US](https://www.amazon.com/dp/B07ZT619TD))
- (Combo) 4x TT马达和轮胎+电线+螺丝 ([US](https://www.amazon.com/dp/B07DRGTCTP))

(仅PCB)

- 1x [自定义PCB](pcb)
- 5条Micro JST PH 2.0电缆([淘宝购买](https://s.click.taobao.com/HYyOTvu))

(可选)

- 测速传感器 Tacho Sensor 3.3V-5V
  - 数量 2
  - 价格:¥3.80
  - [淘宝购买](https://s.click.taobao.com/jMA45xu)
- HC-SR04超声波测距模块传感器
  - 数量 1
  - 价格:¥2.69
  - [淘宝购买](https://s.click.taobao.com/q5545xu)
- 21*15mm 开关
  - 数量 1  
  - 价格:¥1.60
  - [淘宝购买](https://m.tb.cn/h.VzbvV36)
- 5mm发光二极管橘色 (接线需要分压器, 新手不太建议)
  - 数量 2
  - 价格:¥1.98
  - [淘宝购买](https://s.click.taobao.com/rjXJ4xu)

## 制作说明

### 选项1：自己动手做

Wiring Diagram

1. 如有必要，将线连接到电动机
2. 将两个电动机的正极和负极引线插入L298N板的OUT1（+）和OUT2（-）
3. 将其他两个电动机的正极和负极引线插入L298N板的OUT4（+）和OUT3（-）
4. 用4个M3x5螺钉安装L298N，用8个M3x25螺钉和螺母安装电动机。
5. （可选）安装超声波传感器和橙色LED
6. 使用两个M3x25螺钉和螺母将手机支架的底部安装到顶板上
7. 插入手机支架的顶部并安装弹簧或橡皮筋
8. 用一颗M3x5螺钉安装速度传感器
9. 安装电池盒
10. （可选）插入电源开关
11. 将L298N的PWM输入连接到Arduino的引脚D5，D6，D9和D10
12. 将速度传感器和超声波传感器连接到5V和GND
13. 将速度传感器的D0连接到Arduino的D2引脚（左）和D3（右侧）
14. 将超声波传感器的回声和触发器连接到Arduino的D11和D12引脚
15. 将USB电缆连接到Arduino，并将其穿过顶盖
16. （可选）将LED连接到Arduino和GND的D4引脚（左）和D7引脚（右）
17. （可选）将分压器连接至Arduino的A7引脚
18. 将电池电缆连接至L298N的Vin。如果安装了交换机，请将其放在当前路径中。
19. 将六个M3螺母插入底板，然后用六个M3x25螺钉安装顶盖
20. 安装车轮

### 选项2：定制PCB

1. 将带有Micro JST PH 2.0连接器的导线焊接到电机上。
2. 将左边两个电机连接到 M3 和 M4，右边两个电机连接到 M1 和 M2。
3. 用四个 M3x5 螺丝安装 PCB，用八个 M3x25 螺丝和螺母安装电机。
4. 按照DIY选项中的步骤5-10进行。
5. 将LED、速度传感器和超声波传感器连接到PCB上。
6. 将USB电缆连接到Arduino，并将其穿过顶盖。
7. 将电池连接到PCB的Vin（Micro JST PH 2.0连接器）。如果你安装了开关，把它放在电流路径上。
8. 按照DIY选项中的步骤19-20。

## 下一步

烧录[Arduino固件](../firmware/README_CN.md)

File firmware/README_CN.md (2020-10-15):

# 固件

<p align="center">
  <a href="README.md">English</a> |
  <span>简体中文</span>
</p>

我们使用单片机（MCU）充当机器人主体和智能手机之间的桥梁。 我们提供带有ATmega328P微控制器的Arduino Nano的 [固件](openbot_v1_nano/openbot_v1_nano.ino) 用于Arduino Nano与ATmega328P单片机。

## 特性

MCU的主要任务是处理车辆的底层控制，并提供来自底层车载传感器的读数。 MCU通过串行连接接收车辆控制和指示信号。 它将控制转换为电机控制器的PWM信号，并根据指示器信号切换LED。 Arduino程序还通过计算左右前轮上光学传感器的中断来跟踪轮盘旋转。 它通过分压器电路上测量值的缩放移动平均值来计算电池电压。 它还可以通过选配的超声波传感器测量到汽车前方障碍物的距离。 这些测量值通过串口发送回Android应用程序。

## 设置

你只需要在一开始设置好你的硬件配置，以便于代码的编写。如果你做了DIY构建（使用L298N电机驱动），设置`OPENBOT DIY`。
如果你使用了定制的PCB，检查版本并设置`OPENBOT PCB_V1`或`OPENBOT PCB_V2`。

## 依赖

如果要使用超声波传感器，需要安装[NewPing](https://playground.arduino.cc/Code/NewPing)库。

```markdown
Tools
└─── Manage Libraries
```

如果要启用超声波传感器，需要设置`HAS_SONAR 1`。

### 中文克隆Nano（例如美国链接）

您可能需要从芯片制造商（中文）下载[WCH340](http://www.wch.cn/product/CH340.html)驱动程序：

- [Windows](http://www.wch.cn/downloads/CH341SER_EXE.html)
- [Linux](http://www.wch.cn/download/CH341SER_LINUX_ZIP.html)
- [Mac](http://www.wch.cn/download/CH341SER_MAC_ZIP.html)

## 上传

### 设置

- `Tools -> Board -> Arduino AVR Boards -> Arduino Nano`
- `Tools -> Processor -> ATmega328P (Old Bootloader)`
- `Tools -> Port ->  选择USB 端口 `

现在可以通过 `Sketch -> Upload `或按上传按钮（右箭头）上传固件。
固件上传

注意：目前，大多数廉价的Arduino Nano板都带有*Old bootloader*。但是，根据卖家的不同，你也可能会得到一个新的bootloader。所以，如果你无法上传固件，有可能需要将处理器换成*ATmega328P*。

### 测试

本节介绍了固件刷新成功后，如何测试小车的各项功能。

1. 确认
    - 车轮没有连接到汽车上
    - Arduino连接到电脑上
    - 选择正确的USB端口
2. 打开串行监视器：`工具->串行监视器`。

现在您应该看到四个逗号分隔的值，每秒更新一次。

串行监视器

- 第一个值是蓄电池电压。如果您将蓄电池连接到汽车上（即打开开关），它应该显示蓄电池电压。如果您断开蓄电池（即关闭开关），它应该显示一个小值。
- 第二个和第三个值是速度传感器的原始读数。编码器盘上的每个孔都会产生两个计数。您可以通过参数`DISK_HOLES`设置孔的数量。如果您使用的是20个孔的标准盘，那么轮子每转一圈就会有40个计数。因此，如果你把显示的数字除以40，你将得到每秒的转数。
- 第四个值是超声波传感器前的估计可用空间，以cm为单位，默认值为`MAX_DISTANCE`，最大值为`300`。如果禁用超声波传感器，将显示`65535`。

您也可以通过在顶部的输入栏中输入命令，然后按发送键向Arudino发送信息。以下是可用的命令。

- `c<left>,<right>`其中`<left>`和`<right>`都在[-255,255]范围内。`0`值将停止电机。`255`的值是驱动电机全速前进的最大电压。较低的值会导致相应的电压和速度降低。负值应用相应的极性电压，驱动电机反向运行。
- `i<cmd>`其中`<cmd>`的范围是[-1,1]。`-1`值打开左指示灯LED，`1`值打开右指示灯LED。值为`0`则关闭指示灯LED。每次只能有一个状态。

以下测试程序可用于测试该车的所有功能。

1. 打开汽车，观察蓄电池电压。您可以用万用表验证读数，必要时调整`VOLTAGE_DIVIDER_FACTOR`。
2. 如果你安装了超声波传感器。
    a. 将手放在传感器前，前后移动。你应该看到读数有相应的变化。
    b. 确保超声波传感器前面没有任何东西，然后再进行下一步。你应该看到读数为`300`。如果您没有足够的空间，请确保读数至少高于 `STOP_THRESHOLD`，默认为 `64`。
3. 发送命令`c128,128`。电机将以*低速*（50%PWM）开始旋转。速度传感器的读数应该与上图中的数值相似。如果你使用的是DIY版本或电池较弱，数值可能会低一些。检查所有电机是否都在向前旋转。
4. 尝试发送不同的控制，观察速度传感器的读数。例如，命令`c-128,-128`将使所有电机以*低速*（50%PWM）向后旋转。命令`c255,-255`将以*快的速度*(100%PWM)使左电机向前旋转，右电机向后旋转。指令 `c-192,192 `将以*正常速度*(75%PWM)使左电机向后旋转，右电机向前旋转。
5. 将手放在超声波传感器前或发送命令`c0,0`使电机停止。
6. 发送指令`i-1`，观察左侧指示灯闪烁。发送命令`i1`，观察右侧指示灯闪烁。最后，发送命令`i0`，关闭指示灯。

### 无手机模式

在用安装了OpenBot应用的智能手机测试汽车之前，你也可以先测试没有手机的汽车。只需将选项`NO_PHONE_MODE`设置为`1`。汽车现在将以*正常速度*（75%PWM）行驶，当它用超声波传感器检测到障碍物时，会减速。如果它进入`STOP_THRESHOLD`（默认值：64cm）内，它将向右转。注意，汽车和Arduino都需要供电。Arduino可以通过将5V引脚连接到L298N电机驱动器的5V输出端，或者将USB线连接到电源上进行供电。

在让车跑之前，建议先把轮胎拆下来，把Arduino连接到电脑上，像[测试](#测试)一节那样观察串口显示器。输出的数据比较容易理解，可以显示出电池电压、左右电机的转速和车前估计的自由空间。你可以在超声波传感器前来回移动一个大物体，观察电机的速度变化。

警告：如果你没有安装超声波传感器或超声波传感器被禁用，汽车只会以*正常_速度*（75%PWM）向前行驶，会发生碰撞。即使安装了传感器，由于读数有噪音，汽车也会偶尔发生碰撞。

## 使用其他的单片机的需求

您可以使用具有以下功能的任何其他MCU：

- 1个USB到TTL串行（与智能手机通信）
- 4个PWM输出（控制电机）
- 1个模拟ff引脚用于电池监控
- 2个用于速度传感器的数字引脚
- 1个用于超声波传感器的数字引脚（可选）
- 2个用于LED指示灯的数字引脚（可选）

## 下一步

编译并运行[Android App](../android/README_CN.md)

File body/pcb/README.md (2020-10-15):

# Custom PCB

<p align="center">
  <span>English</span> |
  <a href="README_CN.md">简体中文</a>
</p>

The custom PCB acts as a carrier board for the Arduino Nano and integrates modern motor drivers, the voltage divider circuit and resistors for the LEDs. The Arduino is simply plugged into the pin header and all sensors and LEDs are connected via Dupont cables to the appropriate connectors.

PCB_2D
PCB_3D

The latest PCB is [version 2](v2). Here are the changes compared to [version 1](v1):

- Move the right speed sensor to pin D3 to enable interrupt functionality
- Add Power LED for main battery
- Update some components which are more commonly available
- Update voltage divider to 20k/10k for better precision
- Change motor connectors to upright version for easier access

If you have already ordered [version 1](v1) of the PCB ([2D view](../docs/images/pcb_2d_v1.png), [3D view](../docs/images/pcb_3d_v1.png)), don't worry it will work fine. Just make sure to set the correct flag in the firmware.

The custom PCB involves the following steps:

1) **Order the PCB**: Download the [Gerber](v2/gerber_v2.zip) files and order the PCB at the vendor of your choice. You can also order the PCB directly on [PCBWay](https://www.pcbway.com/project/shareproject/OpenBot__Turning_Smartphones_into_Robots.html) where we have shared a project for OpenBot.
2) **Order the components:** Download the [BOM](v2/BOM_v2.csv) and order the compenents at the vendor of your choice, for example [LCSC](https://lcsc.com).
3) **Assembly of the PCB:** You can either assemble the PCB yourself or have them assembled by a vendor. For automated assembly you will need the [Centroid File](v2/centroid_file_v2.csv). If you order the PCB at [JLCPCB](https://jlcpcb.com/), you can use their SMT assembly service. Then you will only need to order and solder the through-hole components yourself. We found this to be the most convenient, cheapest and fastest option. In [version 2](v2) of the PCB, we have updated the components to make sure all of them are available from [JLCPCB](https://jlcpcb.com/) directly.

You can also find vendors that will provide you a TurnKey solution covering all 3 steps. They will manufacture the PCB, source the components and assemble the PCB. This is very convenient and also not too expensive. However, delivery times are often very long (1-3 months).

When requesting a quote at [PCBWay](https://www.pcbway.com/orderonline.aspx), you can select the assembly service after uploading the Gerber file.
Assembly Service
In the next step, you will need to upload the [BOM](v2/BOM_v2.csv) and the [Centroid File](v2/centroid_file_v2.csv). Your quote will then be reviewed and updated within a few days. You can then choose to proceed with payment after reviewing cost and delivery time.

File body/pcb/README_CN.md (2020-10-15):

# 定制PCB

<p align="center">
  <a href="README.md">English</a> |
  <span>简体中文</span>
</p>

定制PCB充当Arduino Nano的载板，并集成了现代电机驱动器，分压器电路和LED电阻器。只需将Arduino插入引脚，所有传感器和LED都通过杜邦线连接到适当的连接器。

PCB_2D
PCB_3D

最新的PCB是[版本2](v2)。以下是与[版本1](v1)相比的更改：

- 将右边的速度传感器移到D3引脚，以实现停止功能
- 为主电池添加电源LED
- 更新一些更常用的组件
- 将分压器更新为20k/10k，以实现更高的精度
- 将电机连接器更改为直立版本，以便于操作

如果您已经订购了PCB的[版本1](v1)([2D视图](../docs/images/pcb_2d_v1.png)，[3D视图](../docs/images/pcb_3d_v1.png) ，请放心，它会正常工作。只要确保在固件中设置正确的标志即可。

定制PCB涉及以下步骤：

1)**订购PCB：** 下载[Gerber](v2/gerber_v2.zip)文件，然后在您选择的供应商处订购PCB。您也可以直接在我们共享了OpenBot项目的[PCBWay](https://www.pcbway.com/project/shareproject/OpenBot__Turning_Smartphones_into_Robots.html)上订购PCB。
2)**订购组件：** 下载[BOM](v2/BOM_v2.csv)并在您选择的供应商处订购组件，例如[LCSC](https://lcsc.com)。
3)**PCB的组装：** 您既可以自己组装PCB，也可以由供应商组装。对于自动组装，您需要[Centroid File](v2/centroid_file_v2.csv)。如果您通过[JLCPCB](https://jlcpcb.com/)订购PCB，则可以使用其SMT组装服务。然后，您只需要自己订购和焊接通孔组件。我们发现这是最方便，最便宜和最快的选择。在PCB的[版本2](v2)中，我们更新了组件，以确保可以从[JLCPCB](https://jlcpcb.com/)直接获得所有组件。

您还可以找到可以为您提供涵盖所有3个步骤的TurnKey解决方案的供应商。他们将制造PCB，采购组件并组装PCB。这非常方便并且也不太昂贵。但是，交货时间通常很长(1-3个月)。

在[PCBWay](https://www.pcbway.com/orderonline.aspx)上请求报价时，可以在上载Gerber文件后选择组装服务。
组装服务
在下一步中，您将需要上传[BOM](v2/BOM_v2.csv)和[Centroid File](v2/centroid_file_v2.csv)。您的报价将在几天之内进行审核和更新。然后，您可以在查看费用和交货时间后选择继续付款。

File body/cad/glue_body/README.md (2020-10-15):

# Glueable Body

<p align="center">
  <span>English</span> |
  <a href="README_CN.md">简体中文</a>
</p>

Some 3D printers have build volumes that are too small to print the full size OpenBot body.
This folder contains the OpenBot body split into 4 pieces.
It can be printed with a build plate as small as 150mmx140mm, and then glued together.

Glueable Body

## Parts

Required parts:

1) `glue_body_bottom_A` ([STL](glue_body_bottom_A.stl), [STEP](glue_body_bottom_A.step))
2) `glue_body_bottom_B` ([STL](glue_body_bottom_B.stl), [STEP](glue_body_bottom_B.step))
3) `glue_body_top_A` ([STL](glue_body_top_A.stl), [STEP](glue_body_top_A.step))
4) `glue_body_top_B` ([STL](glue_body_top_B.stl), [STEP](glue_body_top_B.step))

Optional parts:

These pieces give extra surface area for gluing, which can help if your print experiences warping.

* `glue_connector_bottom` ([STL](glue_connector_bottom.stl), [STEP](glue_connector_bottom.step))
* `glue_connector_top_A` ([STL](glue_connector_top_A.stl), [STEP](glue_connector_top_A.step))
* `glue_connector_top_B` ([STL](glue_connector_top_B.stl), [STEP](glue_connector_top_B.step))

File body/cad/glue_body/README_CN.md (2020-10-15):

# 可粘合机身

<p align="center">
  <a href="README.md">English</a> |
  <span>简体中文</span>
</p>

有些3D打印机的构建体积太小，无法打印完整尺寸的OpenBot本体。
这个文件夹包含了分成4块的OpenBot本体。
它可以用小到150mmx140mm的构建板打印，然后粘合在一起。

可胶合机身

## 部件

必需的部件：

1) `glue_body_bottom_A` ([STL](glue_body_bottom_A.stl), [STEP](glue_body_bottom_A.step))
2) `glue_body_bottom_B` ([STL](glue_body_bottom_B.stl), [STEP](glue_body_bottom_B.step))
3) `glue_body_top_A` ([STL](glue_body_top_A.stl), [STEP](glue_body_top_A.step))
4) `glue_body_top_B` ([STL](glue_body_top_B.stl), [STEP](glue_body_top_B.step))

可选部件：

这些片提供了额外的表面面积来上胶，，如果您的印刷品出现变形，这些部件可以帮助您。

* `glue_connector_bottom`([STL](glue_connector_bottom.stl), [STEP](glue_connector_bottom.step))
* `glue_connector_top_A` ([STL](glue_connector_top_A.stl), [STEP](glue_connector_top_A.step))
* `glue_connector_top_B` ([STL](glue_connector_top_B.stl), [STEP](glue_connector_top_B.step))

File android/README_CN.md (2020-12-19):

# 安卓 App

<p align="center">
  <a href="README.md">English</a> |
  <span>简体中文</span>
</p>

我们的应用程序派生自[TensorFlow Lite object Detection Android Demo](https://github.com/tensorflow/examples/tree/master/lite/examples/object_detection/android)。我们增加了一个数据记录器，并支持游戏控制器与机器人一起收集数据集。目前，我们记录以下传感器的读数：相机、陀螺仪、加速计、磁力计、环境光传感器和气压计。使用Android API，我们可以获得以下传感器读数：RGB图像、角速度、线加速度、重力、磁场强度、光强、大气压力、纬度、经度、海拔、方位和速度。除了手机传感器，我们还记录车身传感器读数(车轮里程计、障碍物距离和电池电压)，这些读数通过串口传输。最后，我们记录从连接的游戏控制器接收道德命令(如果存在)。我们还集成了多个神经网络用于人员跟踪和自主导航。

## 免责声明

1. **安全性：** 一定要确保在安全的环境下操作。请记住，您的手机可能会在碰撞中受损！ **安全：** 一定要确保在安全的环境中操作。在使用自动控制时（如人员跟随或驾驶策略），必须特别小心。确保您始终连接着一个游戏手柄控制器，并熟悉按键映射，以便您可以在任何时候停止车辆。使用时风险自负
2. **应用程序正在开发中：** 应用程序正在开发中，根据您的手机型号和操作系统的版本，可能会崩溃或表现出意外行为。请务必在不连接车轮的情况下测试所有功能。使用时请自行承担风险!

## 开始

### 先决条件

- [Android Studio 3.2或更高版本](https://developer.android.com/studio/index.html)，用于构建和安装apk，否则从[最新版本](https://github.com/intel-isl/OpenBot/releases/latest)的静态资源中下载apk。
- 安卓设备和安卓开发环境，最低API 21。

### 构建
- 如果你使用的是[最新版本](https://github.com/intel-isl/OpenBot/releases/latest)的静态资源中的apk，你可以跳过下面的步骤，直接在手机上[安装](https://www.lifewire.com/install-apk-on-android-4177185)即可。注意，该apk是用调试密钥签名的。
- 打开Android Studio，选择*打开一个现有的Android Studio项目*。
- 选择OpenBot/android目录，点击确定。
- 如果需要的话，确认Gradle Sync。
- 连接你的Android设备，并确保在[开发者选项](https://developer.android.com/studio/debug/dev-options)中启用USB调试。根据你的开发环境，[进一步的步骤](https://developer.android.com/studio/run/device)可能是必要的。
- 单击"运行"按钮（绿色箭头）或从顶部菜单中选择 "运行">"运行'安卓'"。你可能需要使用Build > Rebuild Project来重建项目。
- 如果它要求你使用Instant Run，点击*Proceed Without Instant Run*。

### 代码结构
Tensorlfow Lite目标检测示例程序 [TensorFlow Lite Object Detection Android Demo](https://github.com/tensorflow/examples/tree/master/lite/examples/object_detection/android) 作为集成TFLite模型并获取相机源的起点。 Main activity 是运行主线程的[NetworkActivity](app/src/main/java/org/openbot/NetworkActivity.java)。它继承自管理摄像机和UI的[CameraActivity](app/src/main/java/org/openbot/CameraActivity.java)。[SensorService](app/src/main/java/org/openbot/SensorService.java)读取所有其他电话传感器并记录它们。[env](app/src/main/java/org/openbot/env)文件夹包含实用程序类，如[GameController](app/src/main/java/org/openbot/env/GameController.java)接口和用于声音反馈的[AudioPlayer](app/src/main/java/org/openbot/env/AudioPlayer.java)。[tflite](app/src/main/java/org/openbot/tflite)文件夹包含[Autopilot](app/src/main/java/org/openbot/tflite/Autopilot.java)和[Detector](app/src/main/java/org/openbot/tflite/Detector.java)网络的模型定义。

## 如何使用应用程序

<p align="center">
  App GUI
  App GUI
</p>

### USB连接

下拉菜单用于设置波特率。默认值是115200，你应该不需要改变这个值，除非你把Arduino固件搞乱。该应用程序将尝试自动连接，但如果你遇到问题，你可以使用这个开关来断开/连接。

### 数据记录器

有四种不同的记录模式。

- **only_sensors**。所有传感器数据，但不保存图像
- **crop_img**: 保存所有传感器数据和具有网络输入尺寸的裁剪图像。这是默认设置，是数据收集时应该使用的设置。
- **preview_img**: 保存所有传感器数据和全尺寸图像。这将需要大量的内存，而且速度会很慢。然而，它对于编译FPV视频是很好的。
- **all_imgs**: 所有的传感器数据和裁剪和全尺寸的图像被保存。这将需要大量的内存，而且可能很慢。

右边的开关是用来切换登录和关闭的。在游戏控制器上，这个开关可以用X按钮来切换。

### 驱动模式

在使用游戏控制器（如PS4）时，有三种不同的驱动模式。

- **游戏模式**。使用左右肩部触发器（R2，L2）进行前进和后退油门，任一操纵杆进行转向。该模式模仿赛车电子游戏的控制模式。
- **操纵杆模式**。使用任一操纵杆控制机器人。
- **左右模式**：使用左右操纵杆控制机器人。用左右两根操纵杆分别控制汽车的左右两边 这是原始的差速转向。

右侧的开关用于在游戏控制器和网络之间切换控制。在游戏控制器上，可以使用R1触发按钮切换此开关。

### 车辆控制

有三种不同的速度。

- **慢速**：电机所承受的电压被限制在输入电压的50%（约6V）。
- **正常**：电机所承受的电压被限制在输入电压的75%以内(约9V)。
- **快速**：没有限制。全输入电压将应用于电机 (~12V)。*这是运行神经网络的默认设置*。

以更高的速度运行会降低电机的寿命，但更有乐趣。从连接的游戏控制器接收到的控制或网络预测的控制显示在右侧。

### 模型

该应用程序随附三种模型：

- **DETECTOR_V1_1_0_Q**。此模式用于人员跟踪。它使用MobileNet V1模型的SSD对象检测器。为了在嵌入式设备上获得更好的性能，该模型进行了量化。
- **DETECTOR_V3_S_Q**。该模型用于人员跟踪。它使用MobileNet V3模型的SSD对象检测器。为了提高嵌入式设备的性能，该模型进行了量化。
此模型用于自主导航。它将直接从摄像机输入预测控件。很有可能它在您的环境中不起作用。您应该按照我们的说明来训练自己的[驾驶策略](../ policy)并予以替换。
如果一个模型处于活动状态，它的右侧将显示以[ms]为单位的推理速度。

### 设备

使用下拉菜单选择运行神经网络的设备。您有以下选择。

- **CPU**：使用CPU可以在大多数手机上使用，是默认选择。您可以调整线程数量以优化性能。
- **GPU**：大多数智能手机都具有GPU。具有大量输入（例如图像）的网络通常在GPU上运行得更快。
- **NNAPI**：这将使用[TensorFlow Lite NNAPI delegate](https://www.tensorflow.org/lite/performance/nnapi)。现代智能手机通常会配备专用的AI加速器。[神经网络API](https://developer.android.com/ndk/guides/neuralnetworks)(NNAPI)为Android设备上的TensorFlow Lite模型提供加速，这些设备具有图形处理单元(GPU)、数字信号处理器(DSP)和神经处理单元(NPU)。请注意，在一些较旧的手机上，这可能会非常慢!

## 下一步（可选）

训练自己的[驾驶策略](../policy/README_CN.md)

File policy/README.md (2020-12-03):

# Driving Policy (Advanced)

<p align="center">
  <span>English</span> |
  <a href="README_CN.md">简体中文</a>
</p>

## DISCLAIMERS

1. **Safety:** Driving policies are not perfect and may crash the robot. Always make sure you operate in a safe environment! Keep in mind, that your phone could be damaged in a collision! Make sure you always have a game controller connected and are familiar with the key mapping so you can stop the vehicle at any time. Use at your own risk!
2. **Compute hardware:** Training a driving policy requires a lot of resources and may slow down or even freeze your machine. It is recommended to use a high-end laptop or workstation with large amount of RAM and dedicated GPU, especially when training with larger batch sizes. The documentation is currently also not very detailed. Use at your own risk!
3. **Patience required:** To get a good driving policy for your custom dataset will require some patience. It is not straight-forward, involves data collection, hyperparameter tuning, etc. If you have never trained machine learning models before, it will be challenging and may even get frustrating.

You first need to setup your training environment.

## Dependencies

We recommend to create a conda environment for OpenBot. Instructions on installing conda can be found [here](https://docs.conda.io/projects/conda/en/latest/user-guide/install/).
If you do not have a dedicated GPU (e.g. using your laptop) you can create a new environment with the following command:

```bash
conda create -n openbot python=3.7 tensorflow=2.0.0 notebook=6.1.1 matplotlib=3.3.1 pillow=7.2.0
```

Note that training will be very slow. So if you have access to a computer with dedicated GPU, we highly recommend to use it. In this case, you will need Tensorflow with GPU support. Run the following command to setup the conda environment:

```bash
conda create -n openbot python=3.7 tensorflow-gpu=2.0.0 notebook=6.1.1 matplotlib=3.3.1 pillow=7.2.0
```

If you prefer to setup the environment manually, here is a list of the dependencies:

- Tensorflow
- Jupyter Notebook
- Matplotlib
- Numpy
- PIL

After setting up the conda environment navigate to the folder `policy` within your local OpenBot repository.

NOTES:
- Whenever you want to run the Jupyter notebook you need the activate the environment first: `conda activate openbot`
- If you want to use tensorflow=2.2.0 you may need to pass the custom metrics as custom objects dictionary. (See this [issue](https://github.com/intel-isl/OpenBot/issues/39).)
- If your tensorflow import does not work, try installing via `pip install tensorflow --user`. (See this [issue](https://github.com/intel-isl/OpenBot/issues/98).)

## Data Collection

In order to train an autonomous driving policy, you will first need to collect a dataset. The more data you collect, the better the resulting driving policy. For the experiments in our paper, we collected about 30 minutes worth of data. Note that the network will imitate your driving behaviour. The better and more consistent you drive, the better the network will learn to drive.

1. Connect a bluetooth game controller to the phone (e.g. PS4 controller: to enter pairing mode press the PS and share buttons until the LED flashes quickly).
2. Select the AUTOPILOT_F network in the app.
3. Now drive drive the car via a game controller and record a dataset. On the PS4 controller logging can be toggled with the **X** button.

You will now find a folder called *Openbot* on the internal storage of your smartphone. For each recording, there will be zip file. The name of the zip file will be in the format *yyyymmdd_hhmmss.zip* corresponding to the timestamp of when the recording was started.

The Jupyter notebook expects a folder called `dataset` in the same folder. In this folder, there should be two subfolders, `train_data` and `test_data`. The training data is used to learn the driving policy. The test data is used to validate the learned driving policy on unseen data during the training process. This provides some indication how well this policy will work on the robot. Even though the robot may drive along the same route as seen during training, the exact images observed will be slightly different in every run. The common split is 80% training data and 20% test data. Inside the `train_data` and `test_data` folders, you need to make a folder for each recording session and give it a name such as `my_openbot_1`, `my_openbot_2`, etc. The idea here is that each recording session may have different lighting conditions, a different robot, a different route. In the Jupyter notebook, you can then train only on a subset of these datasets or on all of them. Inside each recording session folder, you drop all the recordings from that recording session. Each recording corresponds to an extracted zip file that you have transferred from the *Openbot* folder on your phone. Your dataset folder should look like this:

folder structure

Rather than copying all files manually from the phone, you can also upload the logs automatically to a [Python server](server/README.md) on your computer. In this case, the zip files will be uploaded and unpacked into the folder `dataset/uploaded`. You will still need to move them into the folder structure for training. You can simply treat the `uploaded` folder as a recording session and move it into `train_data`. The recordings will then be recognized as training data by the Jupyter notebook. If you do not already have a recording session in the `test_data` folder, you also need to move at least one recording from `train_data/uploaded` into `test_data/uploaded`.

## Policy Training

We provide a [Jupyter Notebook](policy_learning.ipynb) that guides you through the steps for training an autonomous driving policy. Open the notebook with the following command.

```bash
jupyter notebook policy_learning.ipynb
```

Now a web-browser window will open automatically and load the Jupyter notebook. Follow the steps in order to train a model with your own data. At the end, two tflite files are generated: one corresponds to the best checkpoint according to the validation metrics and the other to the last checkpoint. Pick one of them and rename it to autopilot_float.tflite. Replace the existing model in Android Studio and recompile the app.

<p align="center">
  App GUI
</p>

If you are looking for the folder in your local directory, you will find it at: `app/src/main/assets/networks`.

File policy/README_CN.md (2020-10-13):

# 驾驶策略(高级)

<p align="center">
  <a href="README.md">English</a> |
  <span>简体中文</span>
</p>

警告：要为您的自定义数据集制定良好的驾驶策略，需要一些耐心。 它不是直接的，涉及数据收集，超参数调整等。如果您以前从未训练过机器学习模型，这将是挑战，甚至可能令人沮丧。

为了训练自动驾驶策略，你首先需要收集一个数据集。你收集的数据越多，得出的驾驶策略就越好。对于我们论文中的实验，我们收集了大约30分钟的数据。注意，网络会模仿你的驾驶行为。你的驾驶行为越好、越稳定，网络就会越好地学习驾驶。

## 数据收集

1. 将蓝牙游戏遥控手柄连接到手机上（如PS4 遥控手柄）。
2. 在应用程序中选择AUTOPILOT_F网络。
3. 现在通过游戏遥控手柄驱动汽车并记录数据集。在PS4控制手柄上可以用 **X** 按钮切换记录。

你现在会在智能手机的内部存储上找到一个名为Openbot的文件夹。对于每个记录，都会有一个压缩文件。zip文件的名称格式为*yyyymmdd_hhmmss.zip*，对应记录开始的时间戳。

你的数据集文件应该以以下结构存储。

```markdown
dataset
└── train_data
 └── my_openbot_1
  └── recording_1
      recording_2
      ...
     my_openbot_2
     ...
 test_data
 └── my_openbot_3
  └── recording_1
      recording_2
      ...
```

从手机上的*Openbot*文件夹中导出，每一条记录都对应着一个解压的压缩文件。

## 训练策略

您首先需要设置您的培训环境。

### 依赖

我们建议为OpenBot创建一个conda环境。关于安装conda的说明可以在[这里](https://docs.conda.io/projects/conda/en/latest/user-guide/install/)找到。

如果你没有专用的GPU（例如使用你的笔记本电脑），你可以用以下命令创建一个新的环境。

```bash
conda create -n openbot python=3.7 tensorflow=2.0.0 notebook=6.1.1 matplotlib=3.3.1 pillow=7.2.0
```

请注意，训练速度会非常慢。所以，如果你具有专用GPU的计算机，我们强烈建议使用它。在这种情况下，你将需要支持GPU的Tensorflow。运行以下命令来设置conda环境。

```bash
conda create -n openbot python=3.7 tensorflow-gpu=2.0.0 notebook=6.1.1 matplotlib=3.3.1 pillow=7.2.0
```

如果你喜欢手动设置环境，这里有一个依赖列表。

- Tensorflow
- Jupyter Notebook
- Matplotlib
- Numpy
- PIL

### Jupyter Notebook

我们提供了一个 [Jupyter Notebook](policy_learning.ipynb)文件，指导您完成训练自动驾驶策略的步骤。笔记本会生成两个`tflite`文件，分别对应根据验证指标的最佳checkpoint和最新checkpoint。选取其中一个并将其重命名为autopilot_float.tflite。替换现有的模型，在

```markdown
app
└── assets
 └── networks
  └── autopilot_float.tflite
```

并重新编译安卓App。

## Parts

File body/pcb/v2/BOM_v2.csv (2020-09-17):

ID | Name | Designator | Footprint | Quantity | Manufacturer Part | Manufacturer | Supplier | Supplier Part | LCSC Assembly
1 | B2B-PH-K-S(LF)(SN) | M2,VIN,M4,M3,M1 | CONN-TH_B2B-PH-K-S | 5 | B2B-PH-K-S(LF)(SN) | JST Sales America | LCSC | C131337
2 | Header-Male-2.54_1x4 | IO1 | DIP-1X4P-2.54MM-M | 1 | C124378 | Ckmtw(Shenzhen Cankemeng) | LCSC | C124378
3 | Header-Male-2.54_1x4 | SONAR | DIP-1X4P-2.54MM-M | 1 | C91552 | BOOMELE(Boom Precision Elec) | LCSC | C91552
4 | 16K | R3,R4 | R0805 | 2 | 0805W8F1602T5E | UNI-ROYAL(Uniroyal Elec) | LCSC | C17490
5 | Header-Male-2.54_1x3 | SPEED_L,SPEED_R | HDR-TH_3P-P2.54-V | 2 | Header2.54mm 1*3P | BOOMELE | LCSC | C49257
6 | Header-Male-2.54_1x10 | IO2 | HDR-TH_10P-P2.54-V | 1 | Headers Pins2.54mm1*10P | BOOMELE(Boom Precision Elec) | LCSC | C57369
7 | 1K | R7 | R0603 | 1 | 0603WAJ0102T5E | UniOhm | LCSC | C25585
8 | ARDUINO_NANO | U1 | ARDUINO_NANO | 2 | C124408 | Ckmtw(Shenzhen Cankemeng) | LCSC | C124408
9 | DRV8871DDAR | U3,U2 | SO-8_L4.9-W3.9-P1.27-LS6.0-BL-EP | 2 | DRV8871DDAR | TI | LCSC | C75864 | Yes
10 | 19-217/R6C-AL1M2VY/3T | LED1 | LED0603-R-RD | 1 | 19-217/R6C-AL1M2VY/3T | EVERLIGHT | LCSC | C72044 | Yes
11 | 100nF | C2,C1 | C0603 | 2 | CC0603KRX7R9BB104 | YAGEO | LCSC | C14663 | Yes
12 | 100uF | C3 | CAP-SMD_BD6.3-L6.6-W6.6-RD | 1 | VEJ101M1VTR-0607 | LELON | LCSC | C176666 | Yes
13 | 150 | R6,R5 | R1206 | 2 | 1206W4F1500T5E | UNI-ROYAL(Uniroyal Elec) | LCSC | C17917
14 | 10K | R2 | R0603 | 1 | ARG03BTC1002 | Viking Tech | LCSC | C309083
15 | Header-Male-2.54_1x2 | U1_VIN,SIGNAL_L,SIGNAL_R | HDR-TH_2P-P2.54-V | 3 | C124375 | Ckmtw(Shenzhen Cankemeng) | LCSC | C124375
16 | 20K | R1 | R0603 | 1 | AR03BTCX2002 | Viking Tech | LCSC | C319766

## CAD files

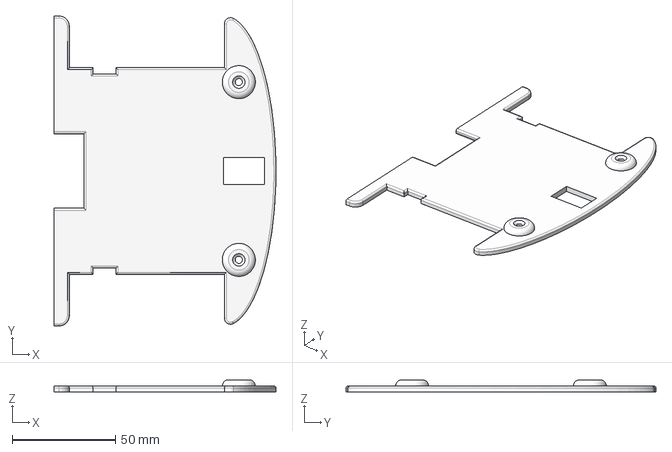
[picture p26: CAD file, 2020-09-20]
body/cad/glue_body/glue_body_top_B.step
107.3 x 150.0 x 6.00 mm

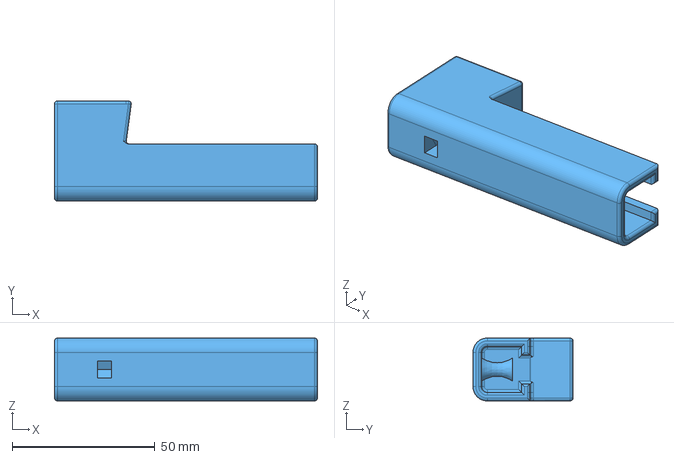
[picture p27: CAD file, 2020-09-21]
body/cad/phone_mount/phone_mount_bottom.step
92.0 x 35.0 x 22.0 mm

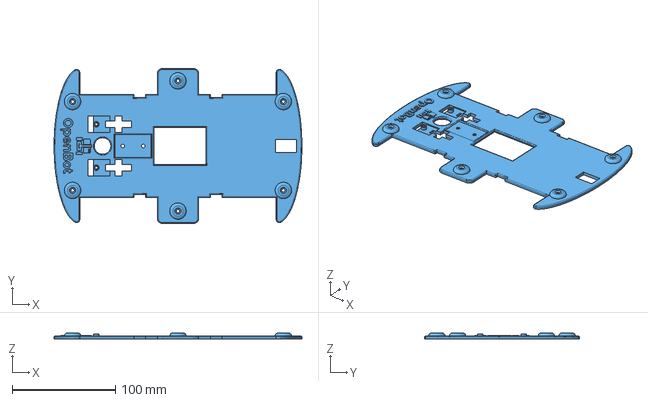
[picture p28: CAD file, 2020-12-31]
body/cad/regular_body/body_top.step
240.0 x 150.0 x 6.00 mm

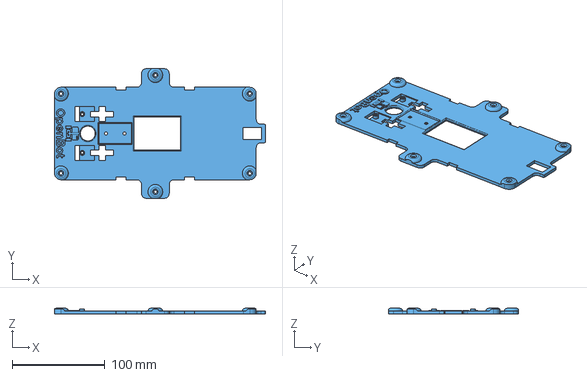
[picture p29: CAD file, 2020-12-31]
body/cad/slim_body/slim_body_top.step
228.0 x 140.0 x 6.00 mm

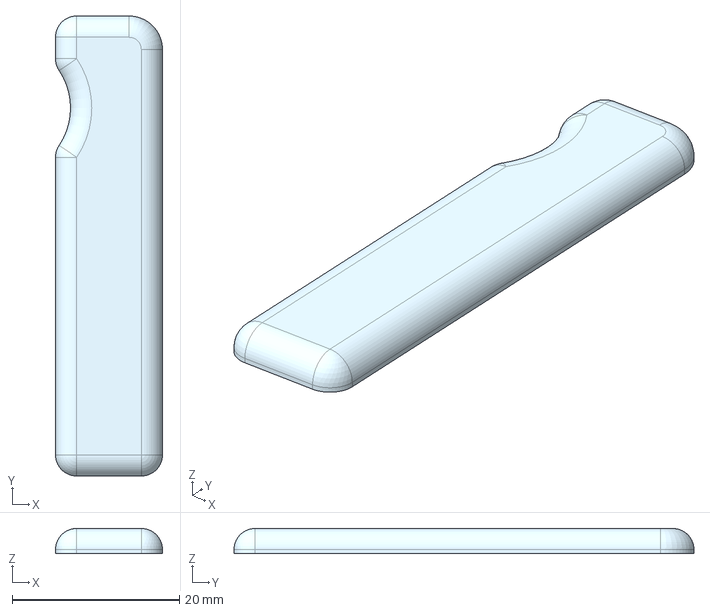
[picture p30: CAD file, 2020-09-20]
body/cad/glue_body/glue_connector_top_A.step
12.8 x 55.0 x 3.00 mm

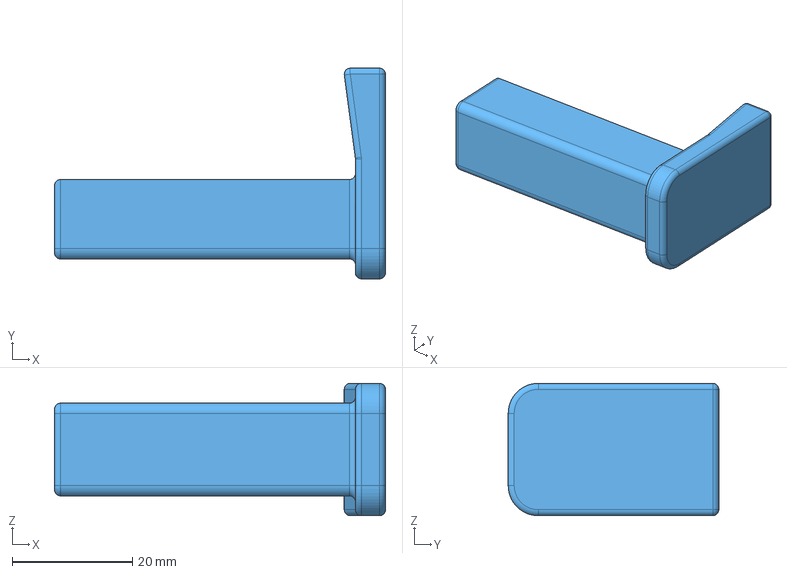
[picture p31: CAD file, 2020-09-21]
body/cad/phone_mount/phone_mount_top.step
55.0 x 35.0 x 22.0 mm

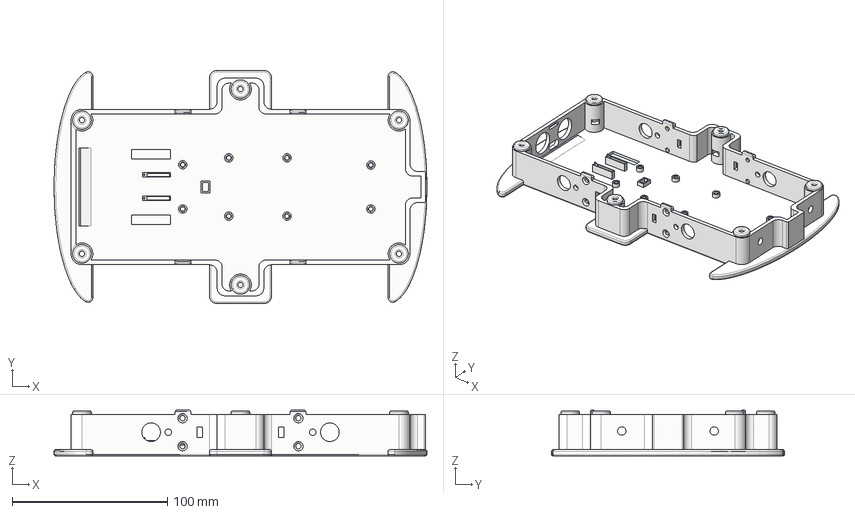
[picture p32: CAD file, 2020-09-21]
body/cad/regular_body/body_bottom.step
240.0 x 150.0 x 29.5 mm

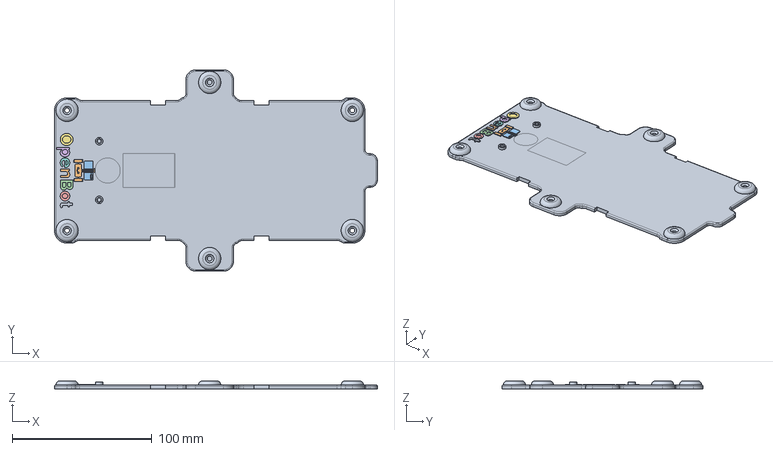
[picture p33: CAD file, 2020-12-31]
body/cad/slim_body/slim_body_top_rim.step
231.0 x 144.0 x 6.00 mm

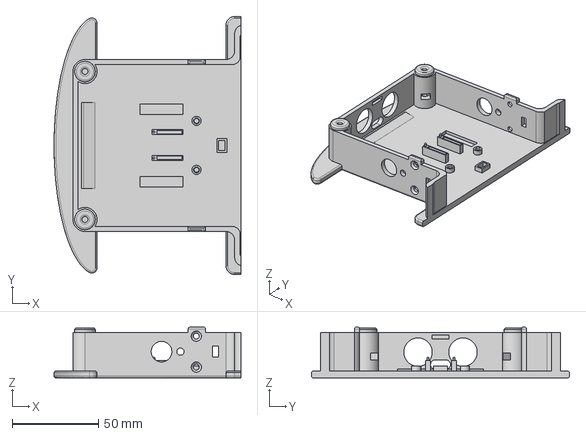
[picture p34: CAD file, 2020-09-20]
body/cad/glue_body/glue_body_bottom_B.step
108.6 x 150.0 x 29.5 mm

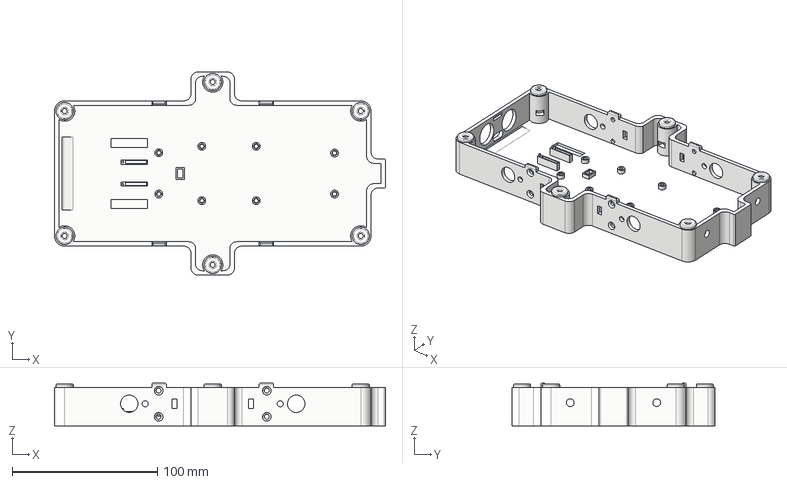
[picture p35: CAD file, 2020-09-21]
body/cad/slim_body/slim_body_bottom.step
228.0 x 140.0 x 29.5 mm

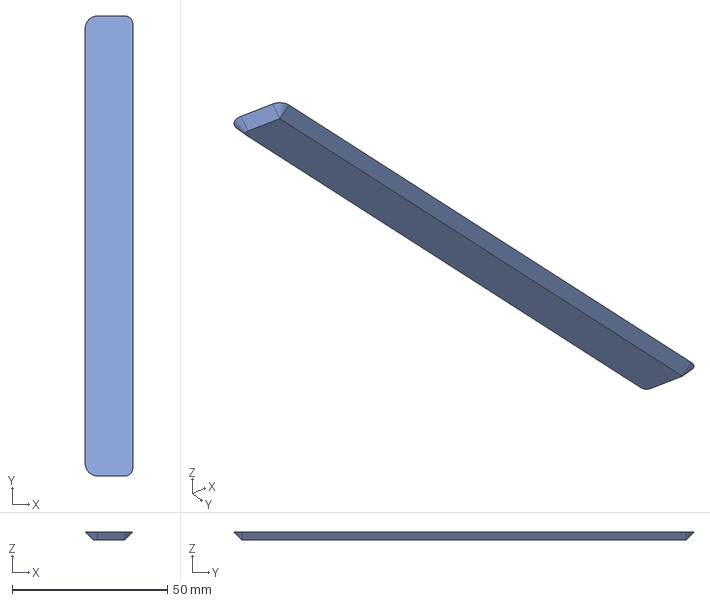
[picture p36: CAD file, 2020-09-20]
body/cad/glue_body/glue_connector_bottom.step
15.3 x 148.0 x 2.54 mm

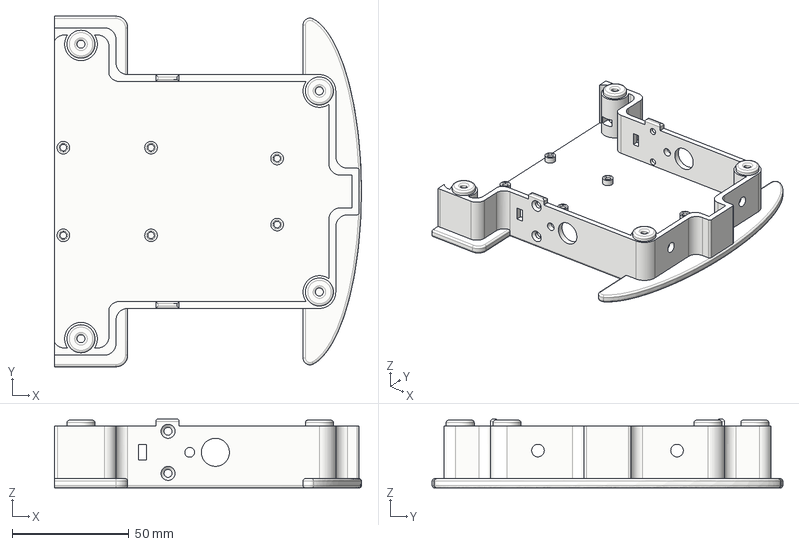
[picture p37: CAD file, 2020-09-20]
body/cad/glue_body/glue_body_bottom_A.step
131.3 x 150.0 x 29.5 mm

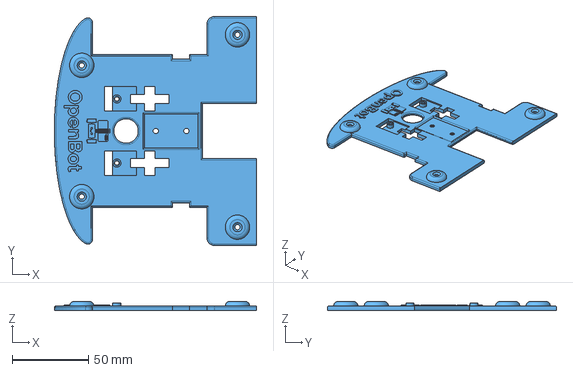
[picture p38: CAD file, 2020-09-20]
body/cad/glue_body/glue_body_top_A.step
132.6 x 150.0 x 6.00 mm

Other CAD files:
body/phone_mount_bottom.step
body/phone_mount_top.step
body/body_bottom.step
body/cad/glue_body/glue_connector_top_B.step
body/cad/glue_body/glue_body_bottom_A.stl
body/cad/glue_body/glue_body_bottom_B.stl
body/cad/glue_body/glue_body_top_A.stl
body/cad/glue_body/glue_body_top_B.stl
body/cad/glue_body/glue_connector_bottom.stl
body/cad/glue_body/glue_connector_top_A.stl
body/cad/glue_body/glue_connector_top_B.stl
body/cad/phone_mount/phone_mount_bottom.stl
body/cad/phone_mount/phone_mount_top.stl
body/cad/regular_body/body_bottom.stl
body/cad/regular_body/body_top.stl
body/cad/slim_body/slim_body_bottom.stl
body/cad/slim_body/slim_body_top.stl
body/cad/slim_body/slim_body_top_rim.stl

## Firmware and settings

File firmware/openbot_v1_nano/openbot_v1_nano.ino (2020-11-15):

// ---------------------------------------------------------------------------
// This Arduino sketch accompanies the OpenBot Android application. 
// By Matthias Mueller, Intelligent Systems Lab, 2020
//
// The sketch has the following functinonalities:
//  - receive control commands from Android application (USB serial)
//. - produce low-level controls (PWM) for the vehicle
//  - toggle left and right indicator signals 
//  - wheel odometry based on optical speed sensors
//  - estimate battery voltage via voltage divider
//  - estimate distance based on sonar sensor 
//  - send sensor readings to Android application (USB serial)
//  - display vehicle status on OLED
//
// Dependencies: Install via "Tools --> Manage Libraries" (type library name in the search field)
//  - Interrupts: PinChangeInterrupt by Nico Hood (read speed sensors and sonar)
//  - OLED: Adafruit_SSD1306 & Adafruit_GFX (display vehicle status)
// Contributors:
//  - October 2020: OLED display support by Ingmar Stapel
// ---------------------------------------------------------------------------

// PIN_PWM_L1,PIN_PWM_L2,PIN_PWM_R1,PIN_PWM_R2  Low-level control of left DC motors via PWM 
// PIN_SPEED_L, PIN_SPEED_R                     Measure left and right wheel speed
// PIN_VIN                                      Measure battery voltage via voltage divider
// PIN_TRIGGER                                  Arduino pin tied to trigger pin on ultrasonic sensor.
// PIN_ECHO                                     Arduino pin tied to echo pin on ultrasonic sensor.
// PIN_LED_LB, PIN_LED_RB                       Toggle left and right rear LEDs (indicator signals) 

//------------------------------------------------------//
// DEFINITIONS
//------------------------------------------------------//

// DO NOT CHANGE!
#define DIY 0
#define PCB_V1 1
#define PCB_V2 2

//------------------------------------------------------//
//SETTINGS
//------------------------------------------------------//

// Setup the OpenBot version (DIY,PCB_V1,PCB_V2)
#define OPENBOT DIY

// Enable/Disable voltage divider (1,0)
#define HAS_VOLTAGE_DIVIDER 0

// Enable/Disable indicators (1,0)
#define HAS_INDICATORS 0

// Enable/Disable speed sensors (1,0)
#define HAS_SPEED_SENSORS 0

// Enable/Disable sonar (1,0)
#define HAS_SONAR 0

// Enable/Disable median filter for sonar measurements (1,0)
#define USE_MEDIAN 0

// Enable/Disable OLED (1,0)
#define HAS_OLED 0

// Enable/Disable no phone mode (1,0)
// In no phone mode:
// - the motors will turn at 75% speed
// - the speed will be reduced if an obstacle is detected by the sonar sensor
// - the car will turn, if an obstacle is detected within STOP_THRESHOLD
// WARNING: If the sonar sensor is not setup, the car will go full speed forward!
#define NO_PHONE_MODE 0

//------------------------------------------------------//
// PINOUT
//------------------------------------------------------//

//Setup the pin definitions
#if (OPENBOT == DIY)
  #define PIN_PWM_L1 5
  #define PIN_PWM_L2 6
  #define PIN_PWM_R1 9
  #define PIN_PWM_R2 10
  #define PIN_SPEED_L 2
  #define PIN_SPEED_R 3
  #define PIN_VIN A7
  #define PIN_TRIGGER 12
  #define PIN_ECHO 11
  #define PIN_LED_LB 4
  #define PIN_LED_RB 7
#elif (OPENBOT == PCB_V1)
  #define PIN_PWM_L1 9
  #define PIN_PWM_L2 10
  #define PIN_PWM_R1 5
  #define PIN_PWM_R2 6
  #define PIN_SPEED_L 2
  #define PIN_SPEED_R 4
  #define PIN_VIN A7
  #define PIN_TRIGGER 3
  #define PIN_ECHO 3
  #define PIN_LED_LB 7
  #define PIN_LED_RB 8
#elif (OPENBOT == PCB_V2)
  #define PIN_PWM_L1 9
  #define PIN_PWM_L2 10
  #define PIN_PWM_R1 5
  #define PIN_PWM_R2 6
  #define PIN_SPEED_L 2
  #define PIN_SPEED_R 3
  #define PIN_VIN A7
  #define PIN_TRIGGER 4
  #define PIN_ECHO 4
  #define PIN_LED_LB 7
  #define PIN_LED_RB 8
#endif

//------------------------------------------------------//
// INITIALIZATION
//------------------------------------------------------//

#include <limits.h>
const unsigned int STOP_THRESHOLD = 32; //cm

#if NO_PHONE_MODE
  int turn_direction = 0; // right
  const unsigned long TURN_DIRECTION_INTERVAL = 2000; // How frequently to change turn direction (ms).
  unsigned long turn_direction_timeout = 0;   // After timeout (ms), random turn direction is updated.
#endif

#if HAS_SPEED_SENSORS or HAS_SONAR
  #include <PinChangeInterrupt.h>
#endif

#if HAS_SONAR
  //Sonar sensor
  const float US_TO_CM = 0.01715; //cm/uS -> (343 * 100 / 1000000) / 2;
  const unsigned long PING_INTERVAL = 100; // How frequently to send out a ping (ms).
  unsigned long ping_timeout = 0;   // After timeout (ms), distance is set to maximum.
  volatile unsigned long start_time = 0; // Time when sending sonar pulse was sent
  volatile unsigned long echo_time = 0; // Time taken to receive echo
  unsigned int distance = UINT_MAX; //cm
  unsigned int distance_estimate = UINT_MAX; //cm
  #if USE_MEDIAN
    const unsigned int distance_array_sz = 3;
    unsigned int distance_array[distance_array_sz]={};
    unsigned int distance_counter = 0;
  #endif
#else
  unsigned int distance_estimate = UINT_MAX; //cm
#endif

#if HAS_OLED
  #include <SPI.h>
  #include <Wire.h>
  #include <Adafruit_GFX.h>
  #include <Adafruit_SSD1306.h>
  
  const int OLED_RESET = -1; // not used
  Adafruit_SSD1306 display(OLED_RESET);
  
  // OLED Display SSD1306
  const unsigned int SCREEN_WIDTH = 128; // OLED display width, in pixels
  const unsigned int SCREEN_HEIGHT = 32; // OLED display height, in pixels
#endif

#if HAS_VOLTAGE_DIVIDER
  const unsigned int ADC_MAX = 1023;
  const unsigned int VREF = 5;
  //The voltage divider factor is computed as (R1+R2)/R2
  #if (OPENBOT == PCB_V1)
    const float VOLTAGE_DIVIDER_FACTOR = (100+33)/33;
  #else //DIY and PCB_V2
    const float VOLTAGE_DIVIDER_FACTOR = (20+10)/10;
  #endif
#endif

//Vehicle Control
int ctrl_left = 0;
int ctrl_right = 0;

//Voltage measurement
const unsigned int VIN_ARR_SZ = 10;
unsigned int vin_counter = 0;
unsigned int vin_array[VIN_ARR_SZ]={0};

//Speed sensor
const unsigned int DISK_HOLES = 20;
volatile int counter_left = 0;
volatile int counter_right = 0;

//Indicator Signal
const unsigned long INDICATOR_INTERVAL = 500; //Blinking rate of the indicator signal (ms).
unsigned long indicator_timeout = 0;
int indicator_val = 0;

//Serial communication
const unsigned long SEND_INTERVAL = 1000; // How frequently vehicle data is sent (ms).
unsigned long send_timeout = 0;
String inString = "";

//------------------------------------------------------//
// SETUP
//------------------------------------------------------//

void setup()
{
  //Outputs
  pinMode(PIN_PWM_L1,OUTPUT);
  pinMode(PIN_PWM_L2,OUTPUT);
  pinMode(PIN_PWM_R1,OUTPUT);
  pinMode(PIN_PWM_R2,OUTPUT);
  pinMode(PIN_LED_LB,OUTPUT);
  pinMode(PIN_LED_RB,OUTPUT);

  //Inputs
  pinMode(PIN_VIN,INPUT);       
  pinMode(PIN_SPEED_L,INPUT);
  pinMode(PIN_SPEED_R,INPUT);
  
  Serial.begin(115200,SERIAL_8N1); //8 data bits, no parity, 1 stop bit
  send_timeout = millis() + SEND_INTERVAL; //wait for one interval to get readings
  
  #if HAS_SPEED_SENSORS
    attachPinChangeInterrupt(digitalPinToPinChangeInterrupt(PIN_SPEED_L), update_speed_left, FALLING);
    attachPinChangeInterrupt(digitalPinToPinChangeInterrupt(PIN_SPEED_R), update_speed_right, FALLING);
  #endif
  
  //Initialize with the I2C addr 0x3C
  #if HAS_OLED
    display.begin(SSD1306_SWITCHCAPVCC, 0x3C);
  #endif
  
  //Test sequence for indicator LEDs
  #if HAS_INDICATORS
    digitalWrite(PIN_LED_LB,LOW);
    digitalWrite(PIN_LED_RB,LOW);
    delay(500);
    digitalWrite(PIN_LED_LB,HIGH);
    delay(500);
    digitalWrite(PIN_LED_LB,LOW);
    digitalWrite(PIN_LED_RB,HIGH);
    delay(500);
    digitalWrite(PIN_LED_RB,LOW);
  #endif
}

//------------------------------------------------------//
// MAIN LOOP
//------------------------------------------------------//

void loop() {
  
  #if HAS_VOLTAGE_DIVIDER
    //Measure voltage
    vin_array[vin_counter%VIN_ARR_SZ] = analogRead(PIN_VIN);
    vin_counter++;
  #endif
  
  #if HAS_SONAR
    //Measure distance every PING_INTERVAL
    if (millis() >= ping_timeout) {
      ping_timeout = ping_timeout + PING_INTERVAL;
      if (echo_time == 0) { //No echo received
        distance = UINT_MAX;
      }
      else
      {
        distance = echo_time * US_TO_CM;
      }
      #if USE_MEDIAN
        distance_array[distance_counter%distance_array_sz] = distance;
        distance_counter++;
        distance_estimate = get_median(distance_array, distance_array_sz);
      #else
        distance_estimate = distance;
      #endif
      send_ping();
    }
  #endif
  
  // Send vehicle measurments to serial every SEND_INTERVAL
  if (millis() >= send_timeout) {
    send_vehicle_data();
    send_timeout = millis() + SEND_INTERVAL;
  }

  #if HAS_INDICATORS
    // Check indicator signal every INDICATOR_INTERVAL
    if (millis() >= indicator_timeout) {
      update_indicators();
      indicator_timeout = millis() + INDICATOR_INTERVAL;
    }
  #endif
  
  #if (NO_PHONE_MODE)
    if (millis() > turn_direction_timeout)
    {
      turn_direction_timeout = millis() + TURN_DIRECTION_INTERVAL;
      turn_direction = random(2); //Generate random number in the range [0,1]
    }
    // drive forward
    if (distance_estimate > 4*STOP_THRESHOLD) {
      ctrl_left = distance_estimate;
      ctrl_right = ctrl_left;
      digitalWrite(PIN_LED_LB, LOW);
      digitalWrite(PIN_LED_RB, LOW);
    }
    // turn slightly
    else if (distance_estimate > 2*STOP_THRESHOLD) {
      ctrl_left = distance_estimate;
      ctrl_right = ctrl_left - 3*STOP_THRESHOLD;
    }
    // turn strongly
    else if (distance_estimate > STOP_THRESHOLD) {
      ctrl_left = 192;
      ctrl_right = - 192;
    }
    // drive backward slowly
    else {
        ctrl_left = -96;
        ctrl_right = -96;
        digitalWrite(PIN_LED_LB, HIGH);
        digitalWrite(PIN_LED_RB, HIGH);
    }
    // flip controls if needed and set indicator light
    if (ctrl_left != ctrl_right) {
      if (turn_direction > 0) {
        int temp = ctrl_left;
        ctrl_left = ctrl_right;
        ctrl_right = temp;
        digitalWrite(PIN_LED_LB, HIGH);
        digitalWrite(PIN_LED_RB, LOW);
      }
      else {
        digitalWrite(PIN_LED_LB, LOW);
        digitalWrite(PIN_LED_RB, HIGH);
      }
    }
    // enforce limits
    ctrl_left = ctrl_left > 0 ? max(64, min(ctrl_left, 192)) : min(-64, max(ctrl_left, -192));
    ctrl_right = ctrl_right > 0 ? max(64, min(ctrl_right, 192)) : min(-64, max(ctrl_right, -192));

  #else // Wait for messages from the phone
    if (Serial.available() > 0) {
      read_msg();
    }
    if (distance_estimate < STOP_THRESHOLD) {
      if (ctrl_left > 0) ctrl_left = 0;
      if (ctrl_right > 0) ctrl_right = 0;
    }
  #endif
  
  update_left_motors();
  update_right_motors();
}


//------------------------------------------------------//
// FUNCTIONS
//------------------------------------------------------//

void update_left_motors() {
    if (ctrl_left < 0) {
      analogWrite(PIN_PWM_L1,-ctrl_left);
      analogWrite(PIN_PWM_L2,0);
    }
    else if (ctrl_left > 0) {
      analogWrite(PIN_PWM_L1,0);
      analogWrite(PIN_PWM_L2,ctrl_left);
    }
    else { //Motor brake
      analogWrite(PIN_PWM_L1,255);
      analogWrite(PIN_PWM_L2,255);
    }
}

void update_right_motors() {
    if (ctrl_right < 0) {
      analogWrite(PIN_PWM_R1,-ctrl_right);
      analogWrite(PIN_PWM_R2,0);
    }
    else if (ctrl_right > 0) {
      analogWrite(PIN_PWM_R1,0);
      analogWrite(PIN_PWM_R2,ctrl_right);
    }
    else { //Motor brake
      analogWrite(PIN_PWM_R1,255);
      analogWrite(PIN_PWM_R2,255);
    }
}

void read_msg() {
  if (Serial.available()) {
    char inChar = Serial.read();
    switch (inChar) {
      case 'c':
        ctrl_left = Serial.readStringUntil(',').toInt();
        ctrl_right = Serial.readStringUntil('\n').toInt();
        break;
      case 'i':
        indicator_val = Serial.readStringUntil('\n').toInt();
        break;
      default:
        break;
    }
  }
}

void send_vehicle_data() {
  float voltage_value = get_voltage();
  int ticks_left = counter_left;
  counter_left = 0;
  int ticks_right = counter_right;
  counter_right = 0;
  
  #if (NO_PHONE_MODE || HAS_OLED)
    float rpm_factor = 60.0*(1000.0/SEND_INTERVAL)/(DISK_HOLES);
    float rpm_left = ticks_left*rpm_factor;
    float rpm_right = ticks_right*rpm_factor;
  #endif
  #if (NO_PHONE_MODE)
    Serial.print("Voltage: "); Serial.println(voltage_value, 2);
    Serial.print("Left RPM: "); Serial.println(rpm_left, 0);
    Serial.print("Right RPM: "); Serial.println(rpm_right, 0);
    Serial.print("Distance: "); Serial.println(distance_estimate);
    Serial.println("------------------");
  #else
    Serial.print(voltage_value);
    Serial.print(",");
    Serial.print(ticks_left);
    Serial.print(",");
    Serial.print(ticks_right);
    Serial.print(",");
    Serial.print(distance_estimate);
    Serial.println();
  #endif 
  
  #if HAS_OLED
    // Set display information
    drawString(
      "Voltage:    " + String(voltage_value,2), 
      "Left RPM:  " + String(rpm_left,0), 
      "Right RPM: " + String(rpm_right, 0), 
      "Distance:   " + String(distance_estimate));
  #endif
}

#if HAS_VOLTAGE_DIVIDER
  float get_voltage () {
    unsigned long array_sum = 0;
    unsigned int array_size = min(VIN_ARR_SZ,vin_counter);
    for(unsigned int index = 0; index < array_size; index++)
    { 
      array_sum += vin_array[index]; 
    }
    return float(array_sum)/array_size/ADC_MAX*VREF*VOLTAGE_DIVIDER_FACTOR;
  }
#else
  float get_voltage () {
    return -1;
  }
#endif

#if HAS_INDICATORS
  void update_indicators() {
    if (indicator_val < 0) {
      digitalWrite(PIN_LED_LB, !digitalRead(PIN_LED_LB));
      digitalWrite(PIN_LED_RB, 0);
    }
    else if (indicator_val > 0) {
      digitalWrite(PIN_LED_LB, 0);
      digitalWrite(PIN_LED_RB, !digitalRead(PIN_LED_RB));
    }
    else {
      digitalWrite(PIN_LED_LB, 0);
      digitalWrite(PIN_LED_RB, 0);
    }
  }
#endif

#if HAS_OLED
// Function for drawing a string on the OLED display
void drawString(String line1, String line2, String line3, String line4) {
  display.clearDisplay();
  // set text color
  display.setTextColor(WHITE);
  // set text size
  display.setTextSize(1);
  // set text cursor position
  display.setCursor(1,0);
  // show text
  display.println(line1);
  display.setCursor(1,8);
  // show text
  display.println(line2);
  display.setCursor(1,16);
  // show text
  display.println(line3);
  display.setCursor(1,24);
  // show text
  display.println(line4);    
  display.display();
}
#endif

#if USE_MEDIAN
  unsigned int get_median(unsigned int a[], unsigned int sz) {
    //bubble sort
    for(unsigned int i=0; i<(sz-1); i++) {
      for(unsigned int j=0; j<(sz-(i+1)); j++) {
        if(a[j] > a[j+1]) {
            unsigned int t = a[j];
            a[j] = a[j+1];
            a[j+1] = t;
        }
      }
    }
    return a[sz/2];
  }
#endif

//------------------------------------------------------//
// INTERRUPT SERVICE ROUTINES (ISR)
//------------------------------------------------------//

#if HAS_SPEED_SENSORS
  // ISR: Increment speed sensor counter (right)
  void update_speed_left() {
    if (ctrl_left < 0) {
      counter_left--; 
    }
    else if (ctrl_left > 0) {
      counter_left++;
    }
  }
  
  // ISR: Increment speed sensor counter (right)
  void update_speed_right() {
    if (ctrl_right < 0) {
      counter_right--; 
    }
    else if (ctrl_right > 0){
      counter_right++;
    }
  }
#endif

#if HAS_SONAR
  // Send pulse by toggling trigger pin
  void send_ping() {
    detachPinChangeInterrupt(digitalPinToPinChangeInterrupt(PIN_ECHO));
    echo_time = 0;
    pinMode(PIN_TRIGGER,OUTPUT);
    digitalWrite(PIN_TRIGGER, LOW);
    delayMicroseconds(5);
    digitalWrite(PIN_TRIGGER, HIGH);
    delayMicroseconds(10);
    digitalWrite(PIN_TRIGGER, LOW);
    pinMode(PIN_ECHO,INPUT);
    attachPinChangeInterrupt(digitalPinToPinChangeInterrupt(PIN_ECHO), start_timer, RISING);
  }
  // ISR: Start timer to measure the time it takes for the pulse to return
  void start_timer() {
    start_time = micros();
    attachPinChangeInterrupt(digitalPinToPinChangeInterrupt(PIN_ECHO), stop_timer, FALLING);
  }
  // ISR: Stop timer and record the time
  void stop_timer() {
    echo_time = micros() - start_time;
    }
#endif

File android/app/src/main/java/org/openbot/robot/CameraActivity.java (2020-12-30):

/*
 * Copyright 2019 The TensorFlow Authors. All Rights Reserved.
 *
 * Licensed under the Apache License, Version 2.0 (the "License");
 * you may not use this file except in compliance with the License.
 * You may obtain a copy of the License at
 *
 *       http://www.apache.org/licenses/LICENSE-2.0
 *
 * Unless required by applicable law or agreed to in writing, software
 * distributed under the License is distributed on an "AS IS" BASIS,
 * WITHOUT WARRANTIES OR CONDITIONS OF ANY KIND, either express or implied.
 * See the License for the specific language governing permissions and
 * limitations under the License.
 */

// Modified by Matthias Mueller - Intel Intelligent Systems Lab - 2020

package org.openbot.robot;

import android.Manifest;
import android.annotation.SuppressLint;
import android.app.Fragment;
import android.content.BroadcastReceiver;
import android.content.ComponentName;
import android.content.Context;
import android.content.Intent;
import android.content.IntentFilter;
import android.content.ServiceConnection;
import android.content.pm.PackageManager;
import android.graphics.Color;
import android.hardware.Camera;
import android.hardware.camera2.CameraAccessException;
import android.hardware.camera2.CameraCharacteristics;
import android.hardware.camera2.CameraManager;
import android.hardware.camera2.params.StreamConfigurationMap;
import android.media.Image;
import android.media.Image.Plane;
import android.media.ImageReader;
import android.media.ImageReader.OnImageAvailableListener;
import android.os.Bundle;
import android.os.Environment;
import android.os.Handler;
import android.os.HandlerThread;
import android.os.IBinder;
import android.os.Message;
import android.os.Messenger;
import android.os.RemoteException;
import android.os.SystemClock;
import android.os.Trace;
import android.util.Log;
import android.util.Size;
import android.view.Surface;
import android.view.View;
import android.view.ViewTreeObserver;
import android.view.WindowManager;
import android.widget.AdapterView;
import android.widget.ArrayAdapter;
import android.widget.CompoundButton;
import android.widget.ImageView;
import android.widget.LinearLayout;
import android.widget.Spinner;
import android.widget.TextView;
import android.widget.Toast;
import androidx.annotation.NonNull;
import androidx.appcompat.app.AppCompatActivity;
import androidx.appcompat.widget.SwitchCompat;
import androidx.appcompat.widget.Toolbar;
import androidx.core.app.ActivityCompat;
import androidx.core.content.ContextCompat;
import androidx.localbroadcastmanager.content.LocalBroadcastManager;
import com.google.android.material.bottomsheet.BottomSheetBehavior;
import java.io.File;
import java.nio.ByteBuffer;
import java.text.SimpleDateFormat;
import java.util.Arrays;
import java.util.Date;
import java.util.Locale;
import java.util.concurrent.TimeUnit;
import org.json.JSONException;
import org.json.JSONObject;
import org.openbot.R;
import org.openbot.common.Constants;
import org.openbot.common.Enums.*;
import org.openbot.env.AudioPlayer;
import org.openbot.env.BotToControllerEventBus;
import org.openbot.env.ControllerToBotEventBus;
import org.openbot.env.GameController;
import org.openbot.env.ImageUtils;
import org.openbot.env.Logger;
import org.openbot.env.PhoneController;
import org.openbot.env.SharedPreferencesManager;
import org.openbot.env.UsbConnection;
import org.openbot.env.Vehicle;
import org.openbot.tflite.Network.Device;
import org.openbot.tflite.Network.Model;
import org.zeroturnaround.zip.ZipUtil;
import org.zeroturnaround.zip.commons.FileUtils;

public abstract class CameraActivity extends AppCompatActivity
    implements OnImageAvailableListener,
        Camera.PreviewCallback,
        CompoundButton.OnCheckedChangeListener,
        View.OnClickListener,
        AdapterView.OnItemSelectedListener {
  private static final Logger LOGGER = new Logger();

  // Constants
  private static final int REQUEST_CAMERA_PERMISSION = 1;
  private static final int REQUEST_LOCATION_PERMISSION_LOGGING = 2;
  private static final int REQUEST_LOCATION_PERMISSION_CONTROLLER = 3;
  private static final int REQUEST_STORAGE_PERMISSION = 4;
  private static final int REQUEST_BLUETOOTH_PERMISSION = 5;

  private static final String PERMISSION_CAMERA = Manifest.permission.CAMERA;
  private static final String PERMISSION_LOCATION = Manifest.permission.ACCESS_FINE_LOCATION;
  private static final String PERMISSION_STORAGE = Manifest.permission.WRITE_EXTERNAL_STORAGE;
  private static final String PERMISSION_BLUETOOTH = Manifest.permission.BLUETOOTH;

  private static Context context;
  private int cameraSelection = CameraCharacteristics.LENS_FACING_BACK;
  protected int previewWidth = 0;
  protected int previewHeight = 0;
  private final boolean debug = false;
  private Handler handler;
  private HandlerThread handlerThread;
  private boolean useCamera2API;
  private boolean isProcessingFrame = false;
  private final byte[][] yuvBytes = new byte[3][];
  private int[] rgbBytes = null;
  private int yRowStride;
  private Runnable postInferenceCallback;
  private Runnable imageConverter;

  private LinearLayout bottomSheetLayout;
  private LinearLayout gestureLayout;
  private BottomSheetBehavior sheetBehavior;

  protected SwitchCompat connectionSwitchCompat,
      networkSwitchCompat,
      logSwitchCompat,
      cameraSwitchCompat;
  protected TextView frameValueTextView,
      cropValueTextView,
      inferenceTimeTextView,
      controlValueTextView;
  protected ImageView bottomSheetArrowImageView;
  private ImageView plusImageView, minusImageView;
  protected Spinner baudRateSpinner,
      modelSpinner,
      deviceSpinner,
      controlModeSpinner,
      driveModeSpinner,
      logSpinner,
      speedModeSpinner;
  private TextView threadsTextView, voltageTextView, speedTextView, sonarTextView;
  private Model model = Model.DETECTOR_V1_1_0_Q;
  private Device device = Device.CPU;
  private int numThreads = -1;

  // **** USB **** //
  protected UsbConnection usbConnection;
  protected boolean usbConnected;
  public int[] BaudRates = {9600, 14400, 19200, 38400, 57600, 115200, 230400, 460800, 921600};
  private int baudRate = 115200;
  private LocalBroadcastManager localBroadcastManager;
  private BroadcastReceiver localBroadcastReceiver;

  protected LogMode logMode = LogMode.CROP_IMG;
  protected ControlMode controlMode = ControlMode.GAMEPAD;
  protected SpeedMode speedMode = SpeedMode.NORMAL;
  protected DriveMode driveMode = DriveMode.GAME;
  protected String logFolder;
  protected boolean loggingEnabled;
  protected boolean networkEnabled = false;
  protected boolean noiseEnabled = false;
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

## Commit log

2020-08-24 Add assembly animation
2020-08-25 Add misc items to BOM
2020-08-26 Update BOM
2020-08-27 Fix STL link
2020-08-28 Add Arduino firmware
2020-08-28 Update README.md
    The Amazon links for the tires and Motor Driver were unavailable. Updated with link that has them in stock.
2020-08-29 Add source source files and slim version
    [body_bottom.step]
2020-08-31 Add PCB instructions
    [BOM.csv, centroid_file.csv]
2020-09-01 Add Chinese Readme file (#12)
    * Add the Chinese lang readme file, update 2 links.
    * Translate custom PCB instruction to Chinese.
    * Translate Android build instruction to Chinese.
2020-09-04 Add wiring diagram
2020-09-04 Update wiring diagram
2020-09-10 Add step files for phone mount
    [phone_mount_bottom.step, phone_mount_top.step]
2020-09-16 Update PCB and READMEs
    [BOM_v1.csv, BOM_v2.csv, centroid_file_v1.csv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]
2020-09-18 Cheaper switch
2020-09-20 Add Glueable Body for printers with small volumes
    [bottom_glue.step, openbot_bottom_A.step, openbot_bottom_B.step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]
2020-09-20 glueing -> gluing
2020-09-21 Adjust slim body, organize files (#52)
    - Adjust slim body to fit on 220x220mm build plate
    - Organize CAD models into folders
    - Organize PCB files into folders
    [BOM_v1.csv, BOM_v2.csv, body_bottom.step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]
2020-09-21 Add info about WCH340 driver (#53)
2020-09-23 Add the standard minimum build plate dimensions
    Adds a line describing what the minimal build plate dimensions should be for the standard (not slim) body.
2020-09-24 Update info about REAME_CN
    switch size fixed, usb cable link fixed, price recommendations for 3d print
2020-09-26 Update firmware and documentation (#60)
    * Refactor and improve the instructions
    * Update firmware and instructions, support PCB_V1 and PCB_V2
    * Refactor: markdown lint
    * Fix some links
    [openbot_v1_nano.ino]
2020-09-29 Fix style and automate style checking
    [CameraActivity.java]
2020-10-07 Update firmware (#77)
    * Stop by sonar
    * No phone mode
    * Refactoring
    * Update documentation
2020-10-13 Update readme (#83)
    * Update README
    * Update pins for DIY build
    * Update wiring diagram
2020-11-09 OLED Display support plus some little changes (#92)
    * Added the functionality for the random left and right turn and additional support for an OLED Display.
    * Some refactoring + added blink sequence during setup to test indicators
    * Revert flags to default
    [openbot_v1_nano.ino]
2020-11-12 Update README.md
    - Add description for alternatives to 3D printing
    - Add OLED links
2020-11-15 major firmware update (#112)
    * several improvements to make code more readable and compact
    * removed NewPing due to many reported issues (e.g. interference on pin 8, pin 3 and 11 not usable as PWM, etc.)
    * implemented interrupt based ultrasonic sensor readings
    * implemented interrupt based speed sensor readings for all hardware configurations
    * all main features/sensors can enabled/disabled with flags so the firmware only contains the functionalities needed and is as fast and extensible as possible
    * improved NO_PHONE_MODE
    [openbot_v1_nano.ino]
2020-11-15 thias15/readme tuning (#113)
    * instructions for getting the code
    * add/update some images
    * compress stl files
2020-11-16 Android bugfix (#114)
    * update gradle and SDK versions
    * fix control in person following for negative sensor rotation
    [CameraActivity.java]
2020-11-19 Button to switch camera (#115)
    * Add camera toggle button and add some logic
    * Dynamic camera toggle button text assignment
    * Persistent camera through orientation changes
2020-12-02 Added SmartPhone drive mode, which starts idsovery of nearby devices.
2020-12-03 WIP: Web server for log uploading (#121)
    * policy: add log upload server with auto ip address resolve
    * android: add upload service, auto upload existing logs when logging started
    * server: unzip logs, generate preview gif
    [CameraActivity.java]
2020-12-06 Handle buttons from controller. Do not handle motion events yet. Now keeps the connection open even if we are re-selecting SmartphoneController.
2020-12-19 revert to previous folder structure
    [CameraActivity.java]
2020-12-30 phone controller (#133)
    * Changed commands format from controller to JSON
    * Two-way communication with phone controller
    * Fixed reversed left-indicator value
    * Add connect/disconnect flags
    [CameraActivity.java]
2020-12-30 switch icon to filled rounded square
2020-12-30 camerax preview integration
2020-12-30 integrate camera base using view binding
2020-12-30 refactor view binding camera methods
2020-12-30 camera fragment reformatting and game fragment default values set
2020-12-31 remove tflite files
    [body_bottom.stl, body_top.step, body_top.stl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]
2021-01-14 GitHub traffic
    [clones.csv, views.csv]
